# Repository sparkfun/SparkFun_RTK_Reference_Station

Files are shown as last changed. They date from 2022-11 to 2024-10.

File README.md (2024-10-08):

SparkFun RTK Reference Station
========================================

<table class="table table-hover table-striped table-bordered">
  <tr align="center">
   <td></td>
  <tr align="center">
    <td><a href="https://www.sparkfun.com/products/22429">SparkFun RTK Reference Station (GPS-22429)</a></td>
  </tr>
</table>

The RTK Reference Station from SparkFun is our most capable GNSS receiver and logger to date. It's your one stop shop for high precision geolocation, surveying and time reference needs. For basic users, it is incredibly easy to get up and running; for advanced users, the Reference Station is a flexible and powerful tool. We took everything we learned while developing our other RTK products, refined it and the Reference Station is the end result.

Is this just a [RTK Facet](https://www.sparkfun.com/products/19984) in a metal box? Oh no! It is _so_ much more... Sure, it is based on the same ESP32-WROOM processor and u-blox ZED-F9P multi-band GNSS module as the Facet. And it runs the same core firmware as the rest of the RTK product family. But there the similarities end. The Reference Station has 10/100 Mbps Ethernet connectivity provided by a WIZnet W5500 and it can be powered by Power-over-Ethernet (PoE) too. With just a few minutes of setup and survey-in, your Reference Station can be serving RTCM correction data to an NTRIP caster of your choice, all via Ethernet!

Need an affordable Network Time Protocol time server for your Ethernet network? We've got you covered. The Reference Station can act as a NTP server. It supports DHCP by default, but you can give it a fixed IP address if you want to. DNS, gateway and subnet mask are all configurable too.

The Reference Station gets a big speed boost too. The microSD card socket is connected via full 4-bit SDIO instead of the usual SPI, providing an order or magnitude improvement in read and write speeds. Similarly, the u-blox ZED-F9P GNSS module is connected via SPI instead of the usual I2C, also providing an order of magnitude improvement in data transfer speeds. Need to log RAWX and SFRBX at 20Hz? You can with the Reference Station!

Repository Contents
-------------------

* [**/Reference_Station_Test_Sketches**](/Reference_Station_Test_Sketches/) - Stand-alone Arduino test sketches for the Reference Station
* [**/Hardware**](/Hardware/) - Eagle PCB files, schematic and dimensions
* [**/Enclosure**](/Enclosure/) - Mechanical drawings for the custom extruded aluminium case and machined panels
* [**/Front_Panel**](/Front_Panel/) - Eagle PCB files for the prototype (fit-check) front panel
* [**/Rear_Panel**](/Rear_Panel/) - Eagle PCB files for the prototype (fit-check) rear panel
* [**/Front_Panel_Sticker**](/Front_Panel_Sticker/) - Drawings and prototype (fit-check) files for the front sticker
* [**/Rear_Panel_Sticker**](/Rear_Panel_Sticker/) - Drawings and prototype (fit-check) files for the rear sticker
* [**/Sticker_Alignment_Jig__Panel**](/Sticker_Alignment_Jig__Panel/) - Eagle PCB files for the two-piece sticker alignment jig
* [**/Sticker_Alignment_Jig__Sticker**](/Sticker_Alignment_Jig__Sticker/) - Eagle PCB files for the two-piece sticker alignment jig

Documentation
--------------

* **[RTK Product Manual](https://docs.sparkfun.com/SparkFun_RTK_Firmware/)** - A detailed guide describing all the various software features of the RTK product line. Essentially it is a manual for the firmware used by the RTK Reference Station.
* **[RTK Reference Station Hookup Guide](https://learn.sparkfun.com/tutorials/sparkfun-rtk-reference-station-hookup-guide)** - Hookup guide for the SparkFun RTK Reference Station.

License Information
-------------------

This product is _**open source**_! 

Please review the LICENSE.md file for license information. 

If you have any questions or concerns on licensing, please contact technical support on our [SparkFun forums](https://forum.sparkfun.com/viewforum.php?f=152).

Distributed as-is; no warranty is given.

- Your friends at SparkFun.

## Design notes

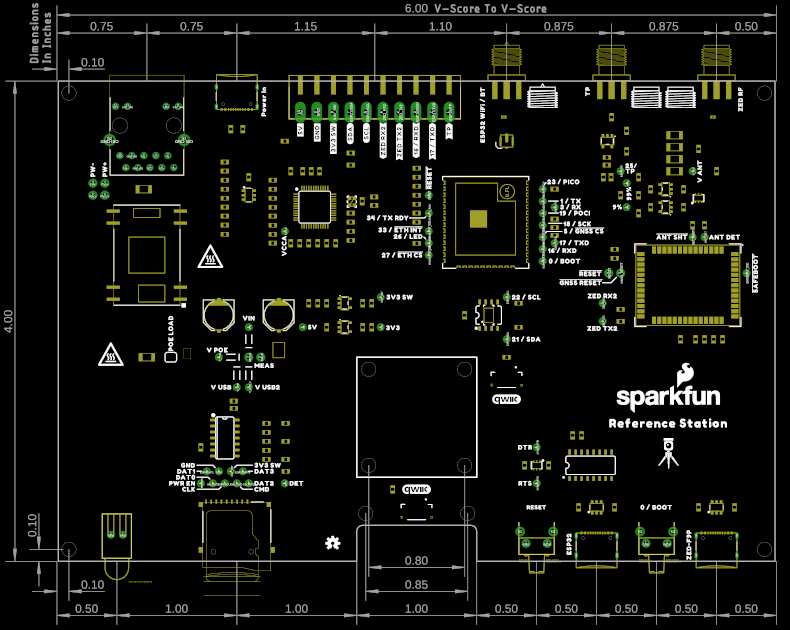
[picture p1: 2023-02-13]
Hardware/Dimensions.png

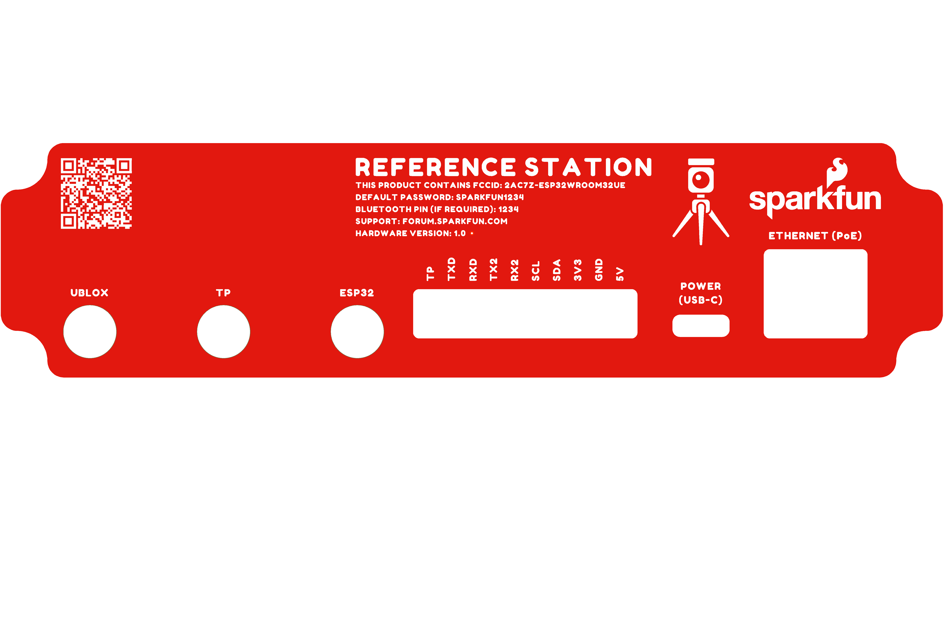
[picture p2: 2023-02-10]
Rear_Panel_Sticker/CORS_Rear_Panel_Sticker.png

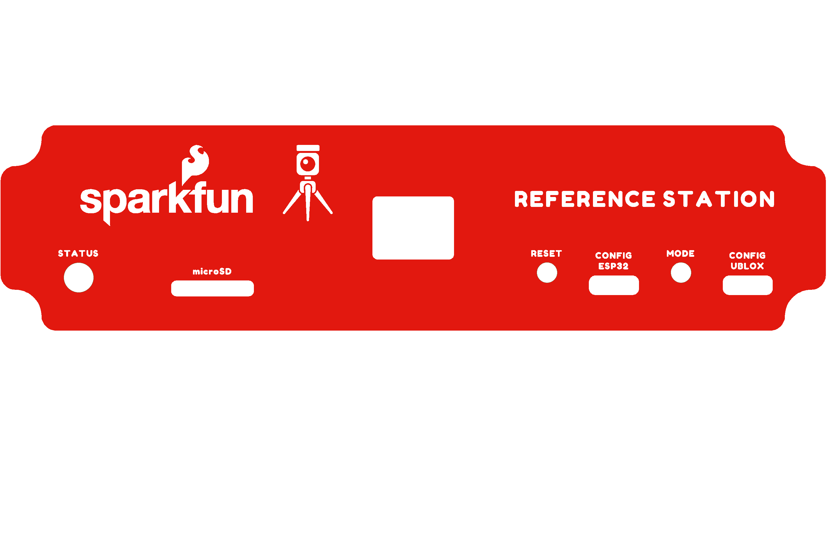
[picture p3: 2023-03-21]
Front_Panel_Sticker/CORS_Front_Panel_Sticker.png

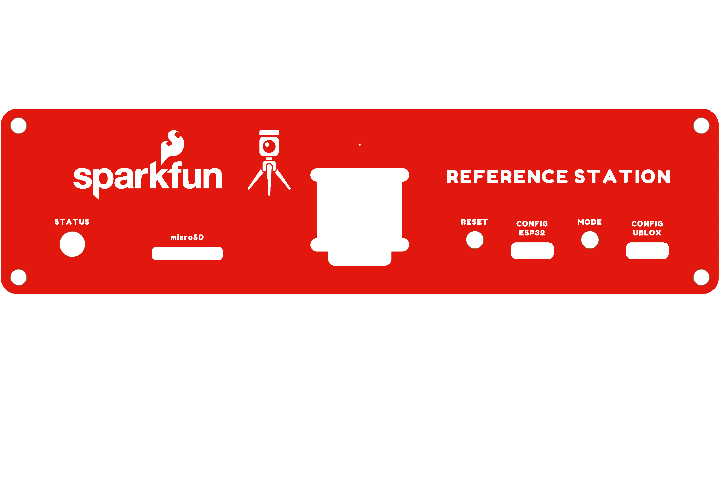
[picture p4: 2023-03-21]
Front_Panel/CORS_Front_Panel.png

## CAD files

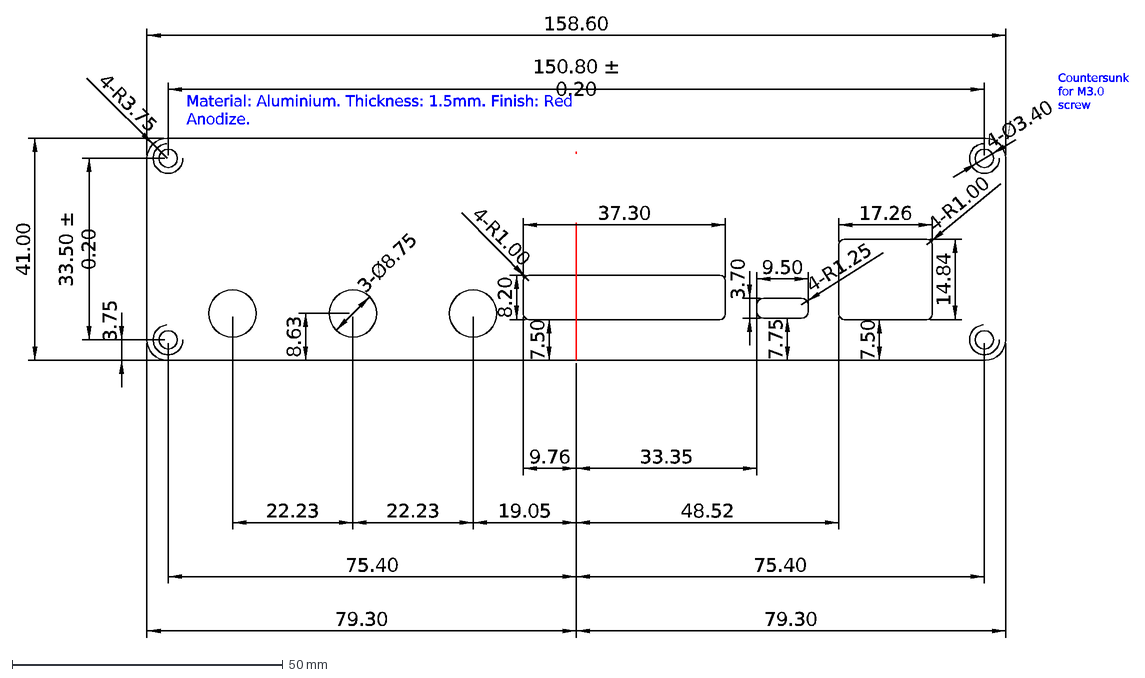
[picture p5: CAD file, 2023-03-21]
Enclosure/SparkFun_HF-A_Custom__Rear_Panel__v3.dxf
158.60
4-R3.75
150.80 ± 0.20
33.50 ± 0.20
41.00
9.76
37.30
7.50
8.20
4-R1.00
33.35
9.50
7.75
3.70
48.52
17.26
14.84
4-R1.25
19.05
22.23
8.63
79.30
75.40
3.75
3-Ø8.75
4-Ø3.40
Countersunk for M3.0 screw
Material: Aluminium. Thickness: 1.5mm. Finish: Red Anodize.

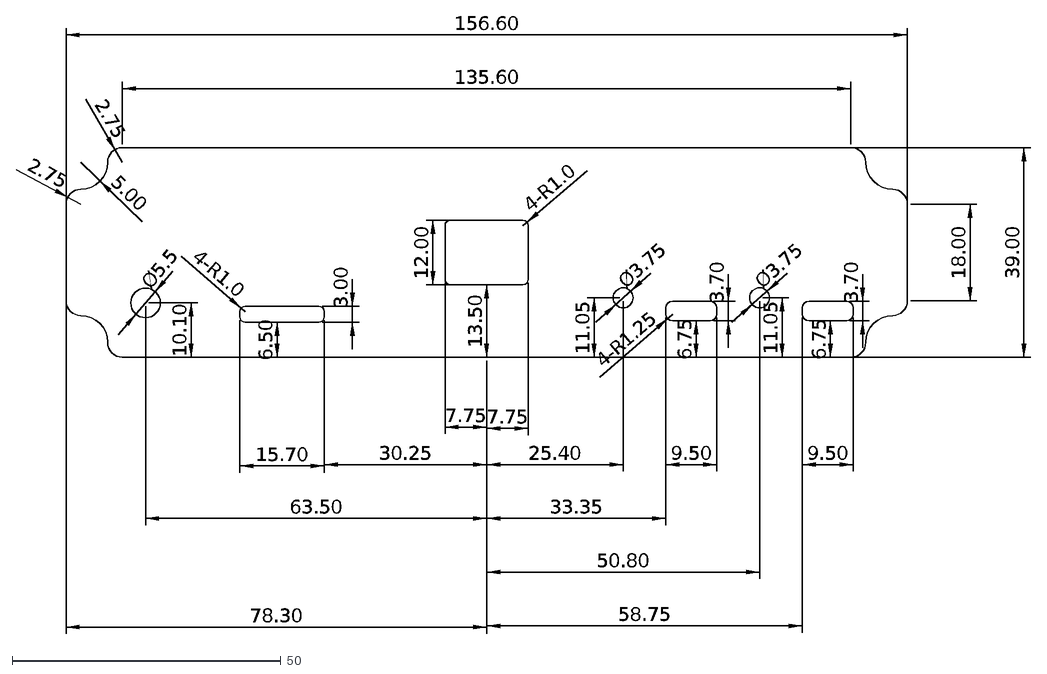
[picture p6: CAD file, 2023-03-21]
Front_Panel_Sticker/Front_Sticker_DXF_R14_v2.dxf
7.75
13.50
12.00
4-R1.0
30.25
15.70
6.50
3.00
63.50
10.10
Ø5.5
25.40
11.05
Ø3.75
33.35
9.50
6.75
3.70
50.80
58.75
78.30
156.60
39.00
2.75
5.00
135.60
18.00
4-R1.25

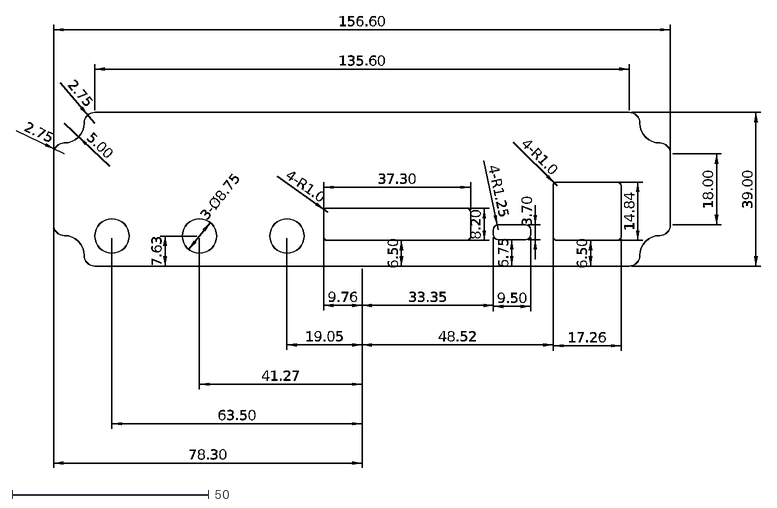
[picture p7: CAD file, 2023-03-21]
Rear_Panel_Sticker/Rear_Sticker_DXF_R14_v2.dxf
9.76
37.30
6.50
8.20
33.35
9.50
6.75
3.70
4-R1.0
19.05
41.27
63.50
7.63
3-Ø8.75
48.52
17.26
14.84
4-R1.25
78.30
135.60
156.60
39.00
18.00
2.75
5.00

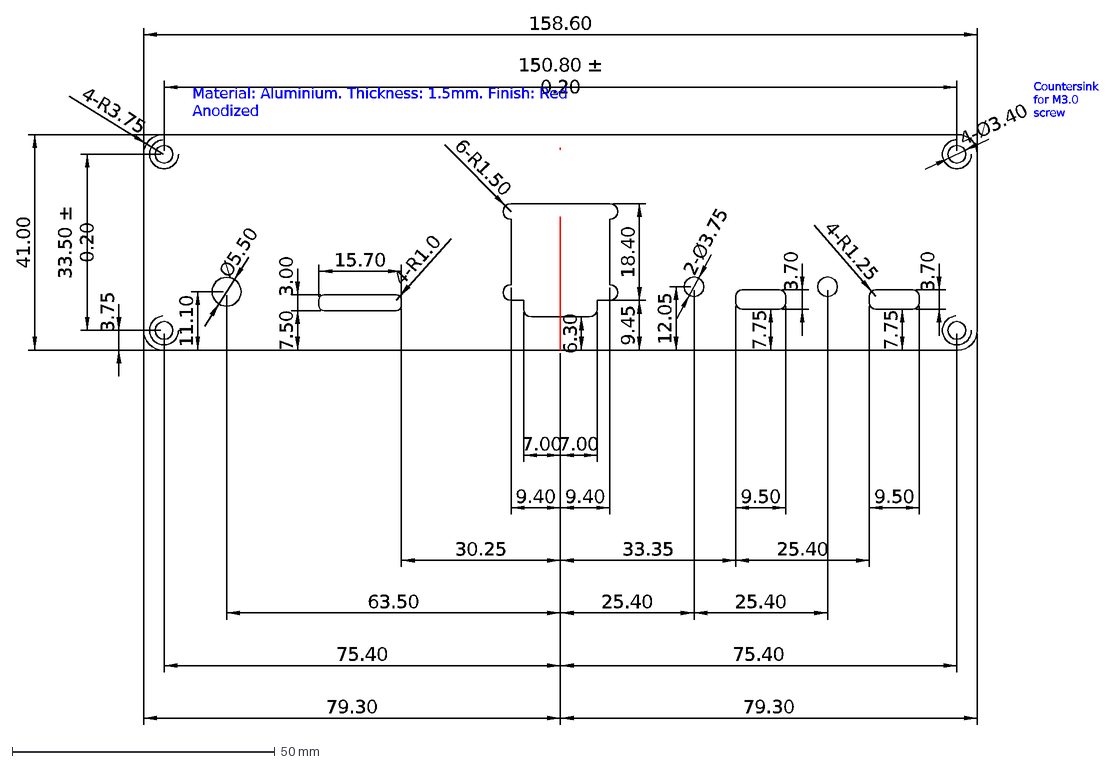
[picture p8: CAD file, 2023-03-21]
Enclosure/SparkFun_HF-A_Custom__Front_Panel__v3.dxf
41.00
158.60
4-R3.75
63.50
11.10
Ø5.50
25.40
3.00
15.70
30.25
7.50
4-R1.0
33.35
9.50
3.70
7.75
4-R1.25
12.05
2-Ø3.75
7.00
9.40
6.30
9.45
18.40
6-R1.50
4-Ø3.40
Countersink for M3.0 screw
33.50 ± 0.20
150.80 ± 0.20
3.75
75.40
79.30
Material: Aluminium. Thickness: 1.5mm. Finish: Red Anodized

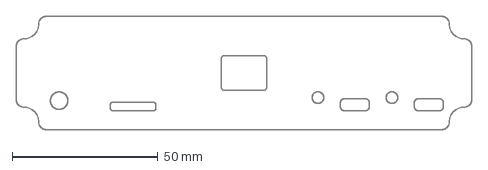
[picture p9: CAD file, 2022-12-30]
Front_Panel_Sticker/CORS_Front_Panel_Sticker.dxf
156.6 x 39.0 mm

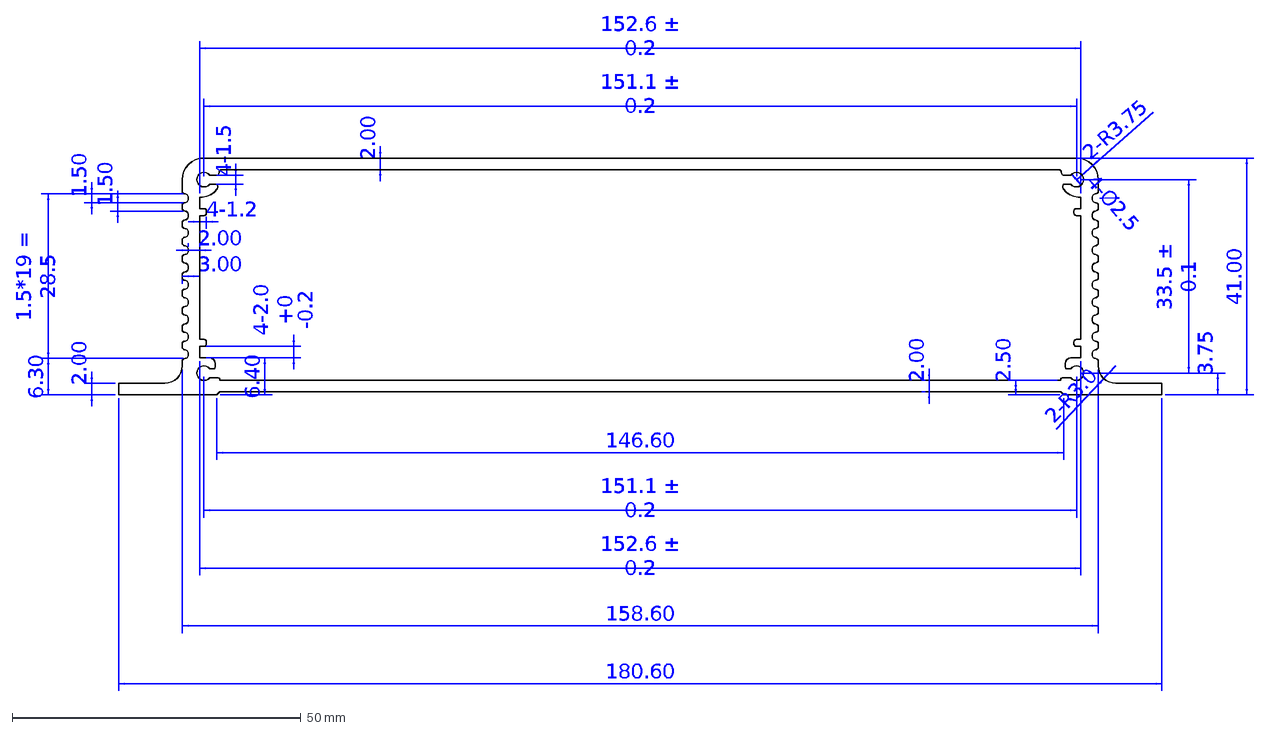
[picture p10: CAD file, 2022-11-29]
Enclosure/SparkFun_HF-A_Custom__Crossection__v3.dxf
1.5*19 = 28.5
6.30
1.50
180.60
158.60
3.00
4-1.5
4-1.2
2.00
2-R3.75
4-Ø2.5
6.40
4-2.0+0^-0.2
151.1 ± 0.2
152.6 ± 0.2
2.50
33.5 ± 0.1
3.75
41.00
146.60
2-R3.0

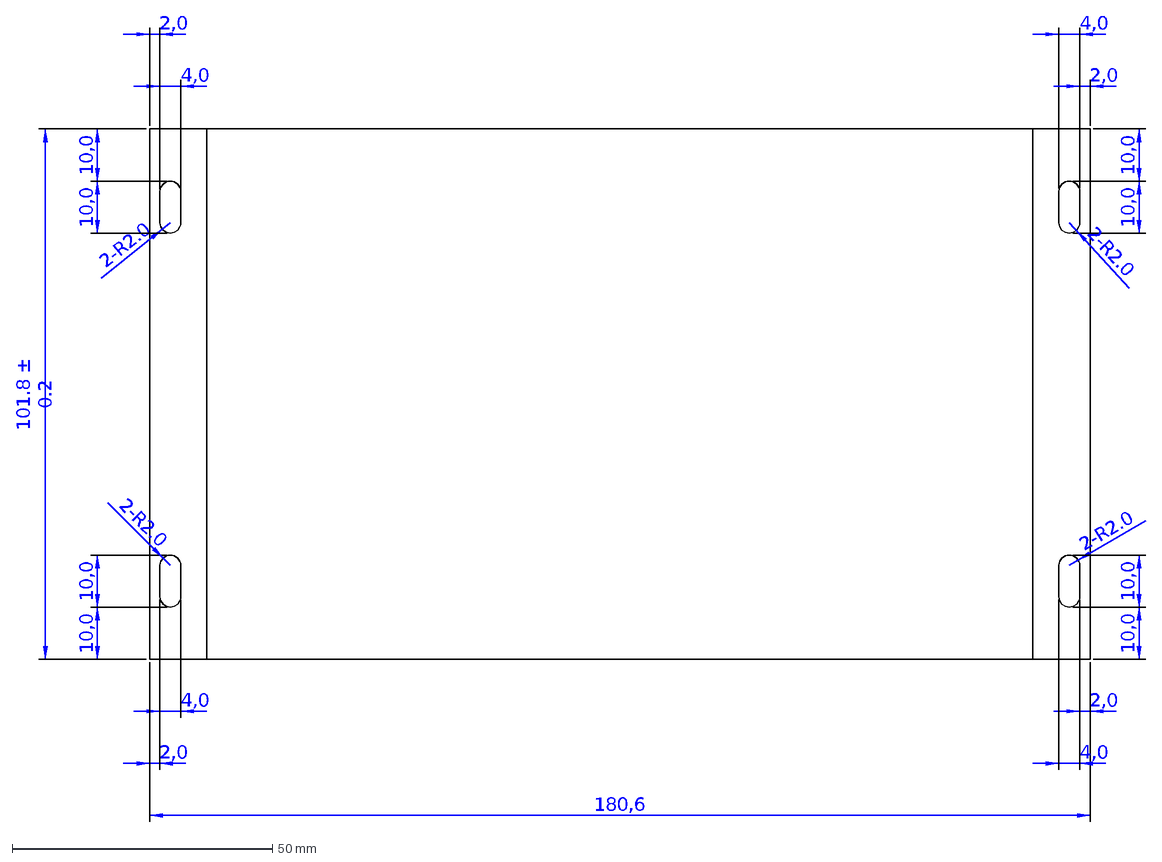
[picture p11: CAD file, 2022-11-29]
Enclosure/SparkFun_HF-A_Custom__Top_View__v3.dxf
101.8 ± 0.2
10,0
4,0
2,0
180,6
2-R2.0

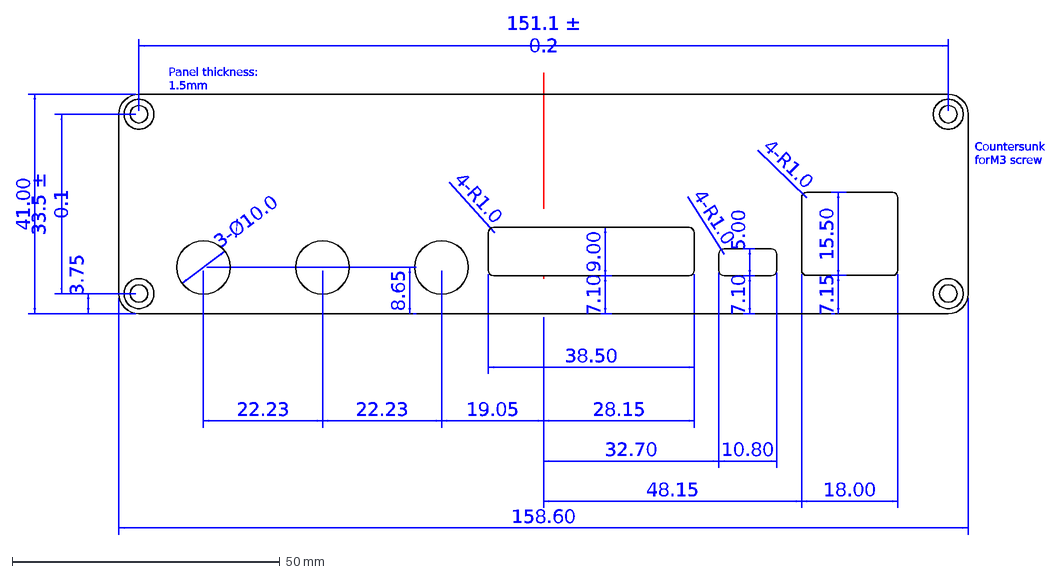
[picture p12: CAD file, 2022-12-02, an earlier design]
Enclosure/SparkFun_HF-A_Custom__Rear_Panel__v2.dxf
19.05
48.15
158.60
18.00
28.15
38.50
Countersunk for M3 screw
Panel thickness: 1.5mm
3.75
41.00
33.5 ± 0.1
151.1 ± 0.2
8.65
3-Ø10.0
4-R1.0
9.00
7.10
15.50
7.15
32.70
10.80
5.00
22.23

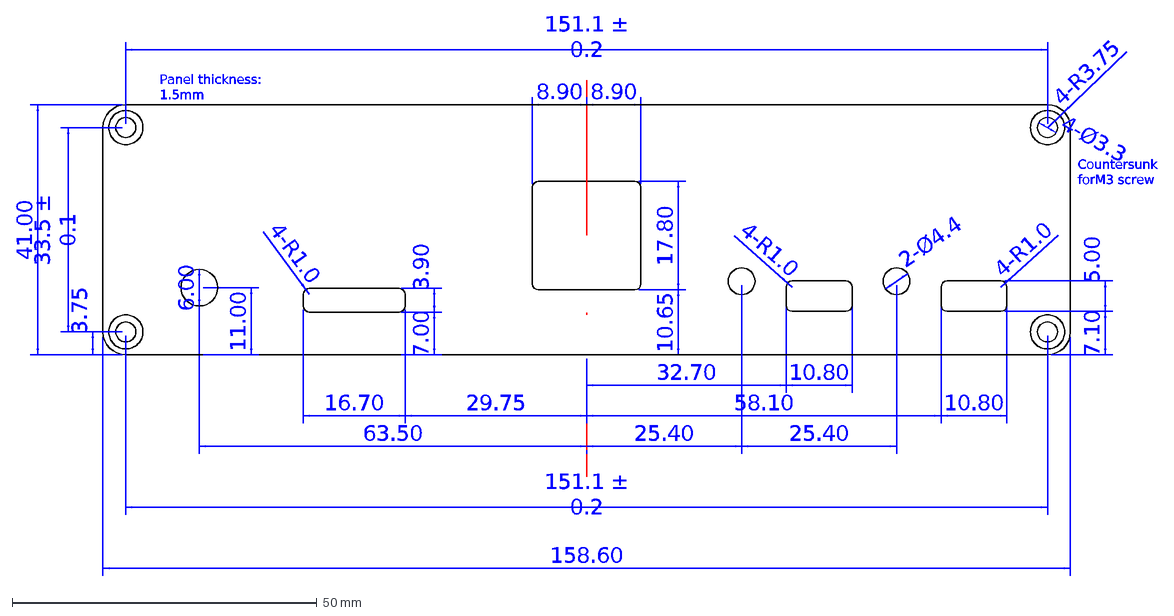
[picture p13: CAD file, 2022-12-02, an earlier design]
Enclosure/SparkFun_HF-A_Custom__Front_Panel__v2.dxf
Countersunk for M3 screw
158.60
63.50
58.10
10.80
8.90
17.80
10.65
32.70
Panel thickness: 1.5mm
41.00
33.5 ± 0.1
151.1 ± 0.2
4-Ø3.3
4-R3.75
11.00
6.00
4-R1.0
5.00
7.10
25.40
2-Ø4.4
29.75
16.70
7.00
3.90
3.75

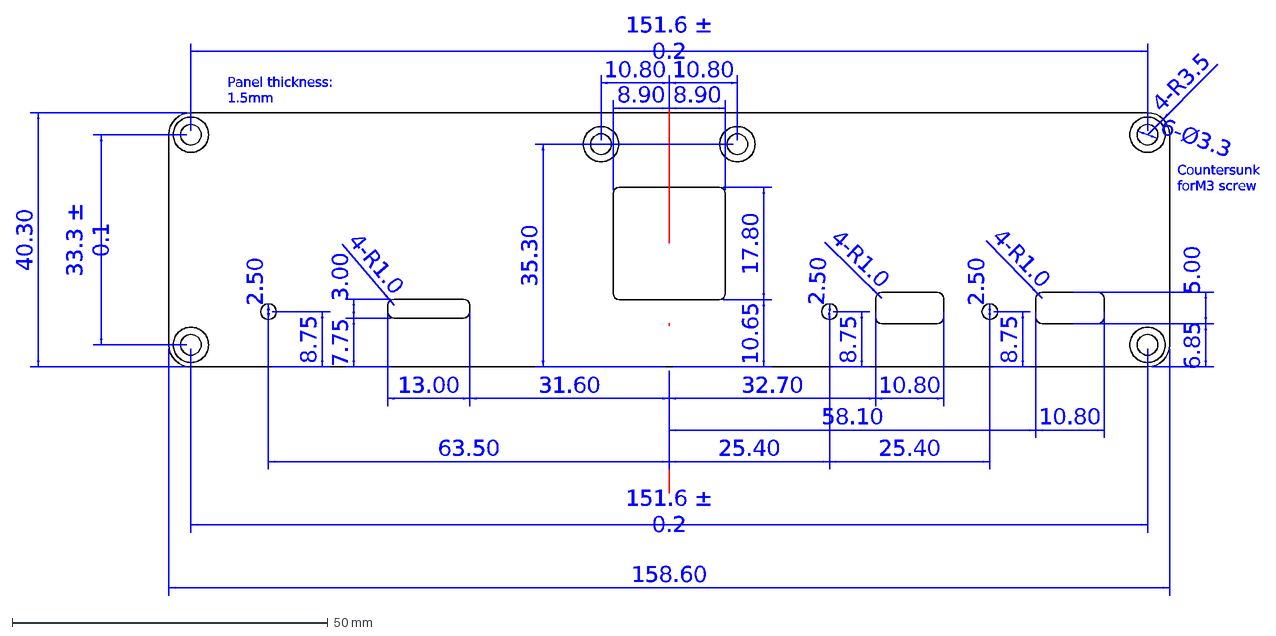
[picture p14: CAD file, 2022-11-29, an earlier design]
Enclosure/SparkFun_HF-A_Custom__Front_Panel.dxf
Countersunk for M3 screw
40.30
158.60
151.6 ± 0.2
63.50
25.40
58.10
10.80
8.75
2.50
4-R1.0
5.00
6.85
6-Ø3.3
4-R3.5
8.90
35.30
17.80
10.65
32.70
31.60
13.00
7.75
3.00
33.3 ± 0.1
Panel thickness: 1.5mm

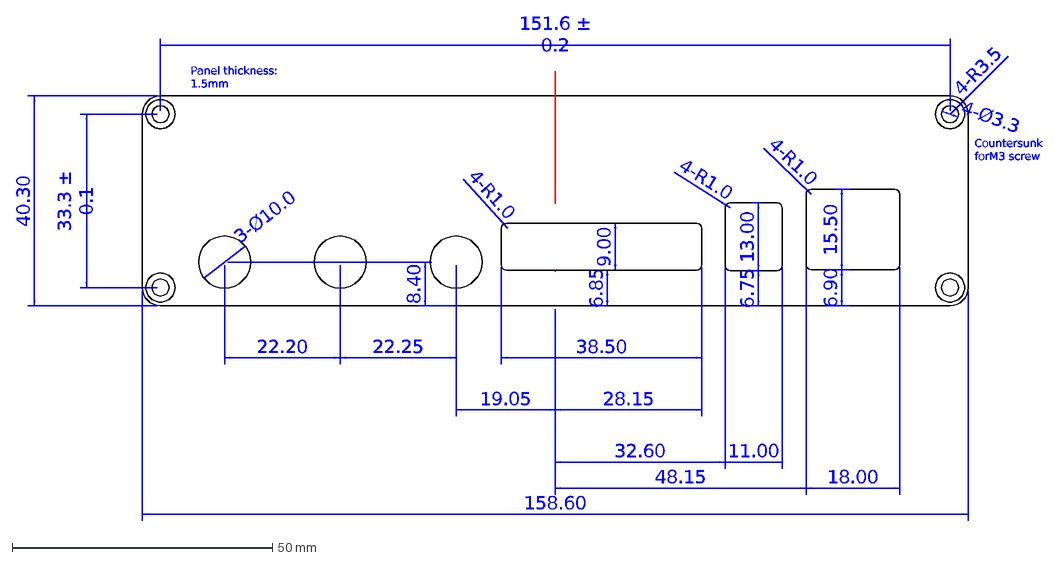
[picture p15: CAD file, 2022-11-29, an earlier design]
Enclosure/SparkFun_HF-A_Custom__Rear_Panel.dxf
40.30
3-Ø10.0
22.20
22.25
8.40
19.05
4-R1.0
9.00
6.85
32.60
48.15
158.60
13.00
6.75
11.00
15.50
6.90
18.00
4-R3.5
4-Ø3.3
151.6 ± 0.2
28.15
38.50
33.3 ± 0.1
Countersunk for M3 screw
Panel thickness: 1.5mm

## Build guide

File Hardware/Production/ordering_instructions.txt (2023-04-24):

panel size, 166x126mm
JLCPCB JLC-7628 Impedance Control
PCB thickness, 1.6mm
number of layers, 4
soldermask color, Red
silkscreen color, White
oz copper, 1oz
finish, HASL lead free
stencils, top
pcs per panel, 1
min trace width, 0.1524mm / 0.0060in
min drill size, 0.3000mm / 0.0118in
filename to layer stackup 1/2/3/4: GTL, GL2, GL3, GBL

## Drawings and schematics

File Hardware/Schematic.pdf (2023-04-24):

# IOA27 12 SCK2/IOA14 13 POCI2/IOA12 14 PICO2/IOA13 16 PICO3/IO23 37 SCL/IO22 36

# TX-IO1 35 RX-IO3 34 SDA/IO21 33 POCI3/IO19 31 SCK3/IO18 30 CS3/IO5 29

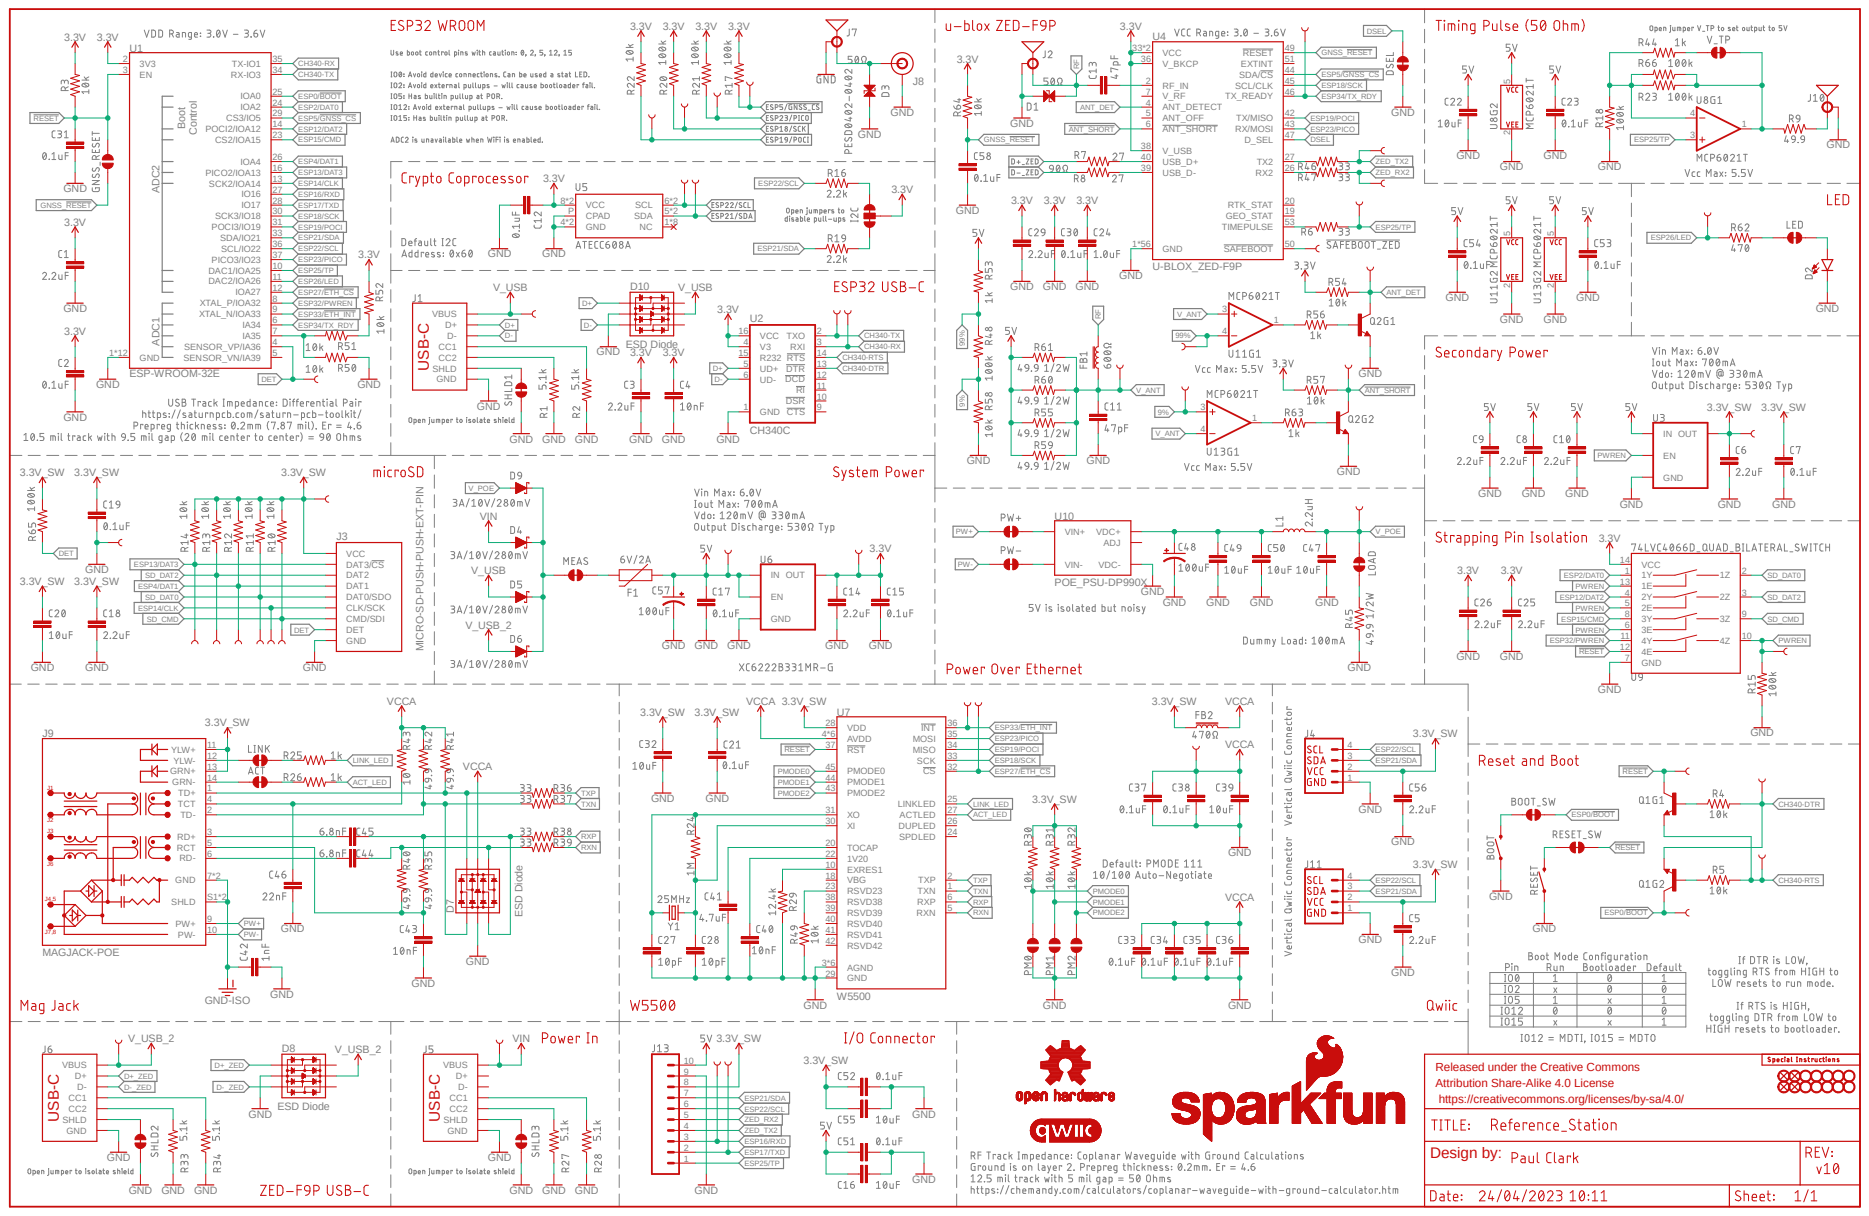
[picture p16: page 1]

DAT2 DAT1 CLK/SCK DET VCC
DAT3/CS CMD/SDI DAT0/SDO

U7 TD+ 1 TCT 4 TD- 2 RD+ 3 RCT 5 RD- 6 GND 7*2 SHLD S1*2 PW+ 9 PW- 10 YLW+ 11 YLW- 12 GRN+ 13 GRN- 14

TXN 1 TXP 2 RXN 5 RXP 6 EXRES1 10 AVDD 4*6 VBG 18 TOCAP 20

Released under the Creative Commons
Attribution Share-Alike 4.0 License
https://creativecommons.org/licenses/by-sa/4.0/

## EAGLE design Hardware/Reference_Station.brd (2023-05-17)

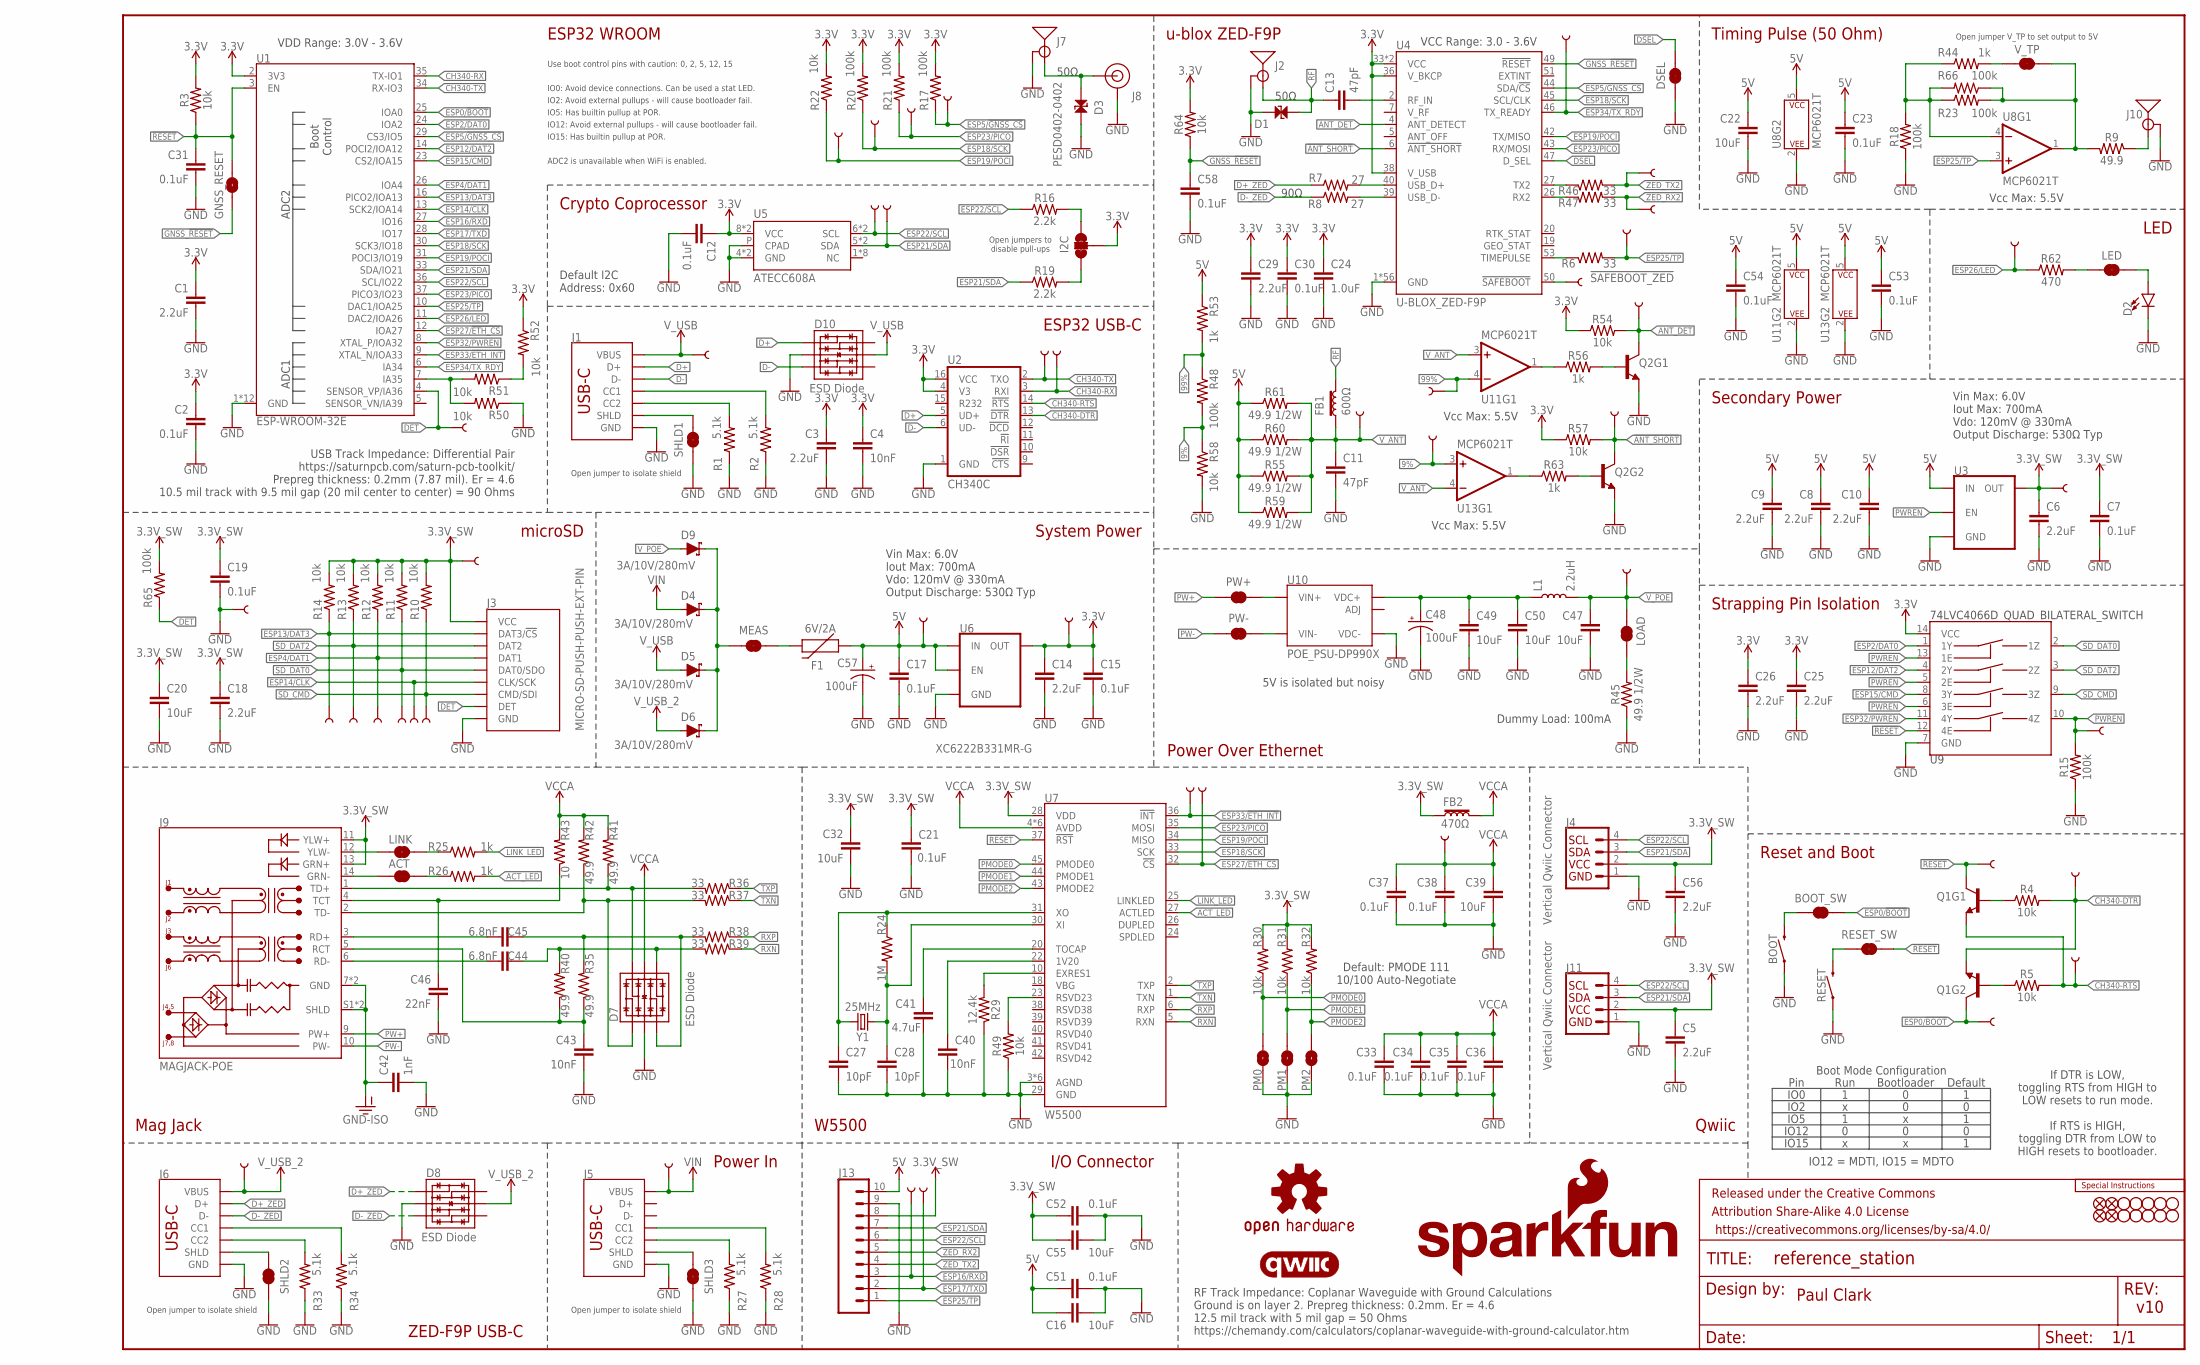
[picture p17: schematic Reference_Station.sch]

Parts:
3V3, 3V3_SW, 5V, 9%, 99%: TEST-POINTPOGO_PTH; 1X01_NO_SILK
!SAFEBOOT_ZED!: TEST-POINTPOGO_PTH; 1X01_NO_SILK
ACT: JUMPER-SMT_2_NC_TRACE_SILK; SMT-JUMPER_2_NC_TRACE_SILK
ANT_DET: TEST-POINTPOGO_PTH; 1X01_NO_SILK
ANT_SHT: TEST-POINTPOGO_PTH; 1X01_NO_SILK
BOOT: MOMENTARY-SWITCH-SPST-PTH-RIGHT-ANGLE-8-020; TACTILE_SWITCH_PTH_RA_8-020
BOOT_SW: JUMPER-SMT_2_NC_TRACE_SILK; SMT-JUMPER_2_NC_TRACE_SILK
C1, C3, C5, C6, C8, C9, C10, C14, C18, C25, C26, C29, C56: 2.2uF; 0603
C2, C7, C12, C15, C17, C19, C21, C23, C30, C31, C33, C34, C35, C36, C37, C38, C51, C52, C53, C54, C58: 0.1uF; 0603
C4, C40, C43: 10nF; 0603
C11, C13: 47pF; 0603
C16, C47, C49, C50: 10uF; 0805
C20, C22, C32, C39, C55: 10uF; 0603
C24: 1.0uF; 0603
C27, C28: 10pF; 0603
C41: 4.7uF; 0603
C42: 1nF; 1206
C44, C45: 6.8nF; 0603
C46: 22nF; 0603
C48, C57: 100uF; PANASONIC_D
CLK: TEST-POINTPOGO_PTH; 1X01_NO_SILK
CMD, CMD1: TEST-POINTPOGO_PTH; 1X01_NO_SILK
D1, D3: PESD0402-0402; 0402
D2: LED-RIGHT-ANGLE-PTH-GREEN; CBI-RIGHT-ANGLE-PTH
D4, D5, D6, D9: 3A/10V/280mV; SOD-323
D7, D8, D10: ESD Diode; SOT-23-6
DAT0, DAT1, DAT2, DAT3: TEST-POINTPOGO_PTH; 1X01_NO_SILK
DET: TEST-POINTPOGO_PTH; 1X01_NO_SILK
DSEL: JUMPER-SMT_2_NC_TRACE_SILK; SMT-JUMPER_2_NC_TRACE_SILK
DTR: TEST-POINTPOGO_PTH; 1X01_NO_SILK
ETH_CS: TEST-POINTPOGO_PTH; 1X01_NO_SILK
ETH_INT: TEST-POINTPOGO_PTH; 1X01_NO_SILK
F1: 6V/2A; 1210
FB1: 600Ω; 0805
FB2: 470Ω; 0603
FD1, FD2, FD3, FD4: FIDUCIAL1X2; FIDUCIAL-1X2
FRAME1: FRAME-LEDGER; CREATIVE_COMMONS
GND: TEST-POINTPOGO_PTH; 1X01_NO_SILK
GNSS_CS: TEST-POINTPOGO_PTH; 1X01_NO_SILK
GNSS_RESET: JUMPER-COMBO_2_NO; COMBO-JUMPER_2_NO
H1, H2, H3, H4, H5, H6, H7, H8, H9, H10: STAND-OFFTIGHT; STAND-OFF-TIGHT
I2C: JUMPER-SMT_3_2-NC_TRACE_SILK; SMT-JUMPER_3_2-NC_TRACE_SILK
J1, J5, J6: USB_C_4-LAYER_PADS; USB-C-16P_4LAYER-PADS
J2, J10: ANTENNA-SMA-GROUNDEDEDGE_SMA; SMA-EDGE
J3: MICRO-SD-PUSH-PUSH-EXT-PIN; MICROSD-EXTERNALPIN
J4, J11: Vertical Qwiic Connector; JST04_1MM_VERT
J7: ANTENNA-SMA-GROUNDEDEDGE_RPSMA; RP-SMA-EDGE
J8: U.FL2PIN-REDUCED-FOOTPRINT; U.FL_REDUCED_FOOTPRINT
J9: MAGJACK-POE; MAGJACK-SYM_LED
J13: CONN_10_3.5MM_RA_HEADER; 1X10_SCREW_TERMINAL_3.5MM
L1: 2.2uH; 0805-WIDE
LED: JUMPER-SMT_2_NC_TRACE_SILK; SMT-JUMPER_2_NC_TRACE_SILK
LINK: JUMPER-SMT_2_NC_TRACE_SILK; SMT-JUMPER_2_NC_TRACE_SILK
LOAD: JUMPER-SMT_2_NC_TRACE_SILK; SMT-JUMPER_2_NC_TRACE_SILK
LOGO1: SPECIAL_INSTRUCTIONS-ORDERING; ORDERING_INSTRUCTIONS
LOGO3: QWIIC_LOGO_6MM; QWIIC_6MM
LOGO4: OSHW-LOGOS; OSHW-LOGO-S
LOGO5: SFE_LOGO_NAME.2_INCH; SFE_LOGO_NAME_.2
LOGO6: SFE_LOGO_FLAME.2_INCH; SFE_LOGO_FLAME_.2
MEAS: JUMPER-COMBO_2_NC_TRACE; COMBO-JUMPER_2_NC_TRACE
PICO: TEST-POINTPOGO_PTH; 1X01_NO_SILK
PM0, PM1, PM2: JUMPER-SMT_2_NO_SILK; SMT-JUMPER_2_NO_SILK
POCI: TEST-POINTPOGO_PTH; 1X01_NO_SILK
PW+: JUMPER-COMBO_2_NC_TRACE; COMBO-JUMPER_2_NC_TRACE
PW-: JUMPER-COMBO_2_NC_TRACE; COMBO-JUMPER_2_NC_TRACE
PWREN: TEST-POINTPOGO_PTH; 1X01_NO_SILK
Q1, Q2: TRANS_NPN_DUAL-MBT3904DW1T1; SC70-6
R1, R2, R27, R28, R33, R34: 5.1k; 0603
R3, R4, R5, R10, R11, R12, R13, R14, R22, R30, R31, R32, R49, R50, R51, R52, R54, R57, R58, R64: 10k; 0603
R6, R36, R37, R38, R39, R46, R47: 33; 0603
R7, R8: 27; 0603
R9, R35, R40, R41, R42: 49.9; 0603
R15, R17, R18, R20, R21, R23, R48, R65, R66: 100k; 0603
R16, R19: 2.2k; 0603
R24: 1M; 0603
R25, R26, R44, R53, R56, R63: 1k; 0603
R29: 12.4k; 0603
R43: 10; 0603
R45, R55, R59, R60, R61: 49.9 1/2W; 1206
R62: 470; 0603
RESET: MOMENTARY-SWITCH-SPST-PTH-RIGHT-ANGLE-8-020; TACTILE_SWITCH_PTH_RA_8-020
RESET_SW: JUMPER-SMT_2_NC_TRACE_SILK; SMT-JUMPER_2_NC_TRACE_SILK
RTS: TEST-POINTPOGO_PTH; 1X01_NO_SILK
RX, RX2: TEST-POINTPOGO_PTH; 1X01_NO_SILK
RXD: TEST-POINTPOGO_PTH; 1X01_NO_SILK
SCK: TEST-POINTPOGO_PTH; 1X01_NO_SILK
SCL: TEST-POINTPOGO_PTH; 1X01_NO_SILK
SDA: TEST-POINTPOGO_PTH; 1X01_NO_SILK
SHLD1, SHLD2, SHLD3: JUMPER-SMT_2_NC_TRACE_SILK; SMT-JUMPER_2_NC_TRACE_SILK
TP: TEST-POINTPOGO_PTH; 1X01_NO_SILK
TP_BOOT: TEST-POINTPOGO_PTH; 1X01_NO_SILK
TP_LED: TEST-POINTPOGO_PTH; 1X01_NO_SILK
TP_RESET: TEST-POINTPOGO_PTH; 1X01_NO_SILK
TX, TX2: TEST-POINTPOGO_PTH; 1X01_NO_SILK
TXD: TEST-POINTPOGO_PTH; 1X01_NO_SILK
TX_RDY: TEST-POINTPOGO_PTH; 1X01_NO_SILK
U1: ESP-WROOM-32E; ESP-WROOM-32EU
U2: CH340C; SO016
U3, U6: XC6222B331MR-G; SOT23-5
U4: U-BLOX_ZED-F9P; ZED-F9P
U5: ATECC608A; DUAL_UDFN_2X3MM_SOIC-8
U7: W5500; LQFP-48
U8, U11, U13: MCP6021T; SOT23-5
U9: 74LVC4066D_QUAD_BILATERAL_SWITCH; SO14
U10: POE_PSU-DP990X; DP990X
VANT: TEST-POINTPOGO_PTH; 1X01_NO_SILK
VCCA: TEST-POINTPOGO_PTH; 1X01_NO_SILK
VIN: TEST-POINTPOGO_PTH; 1X01_NO_SILK
VPOE: TEST-POINTPOGO_PTH; 1X01_NO_SILK
VUSB, VUSB2: TEST-POINTPOGO_PTH; 1X01_NO_SILK
V_TP: JUMPER-SMT_2_NC_TRACE_SILK; SMT-JUMPER_2_NC_TRACE_SILK
Y1: 25MHz; CRYSTAL-SMD-2.0X1.6MM

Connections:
3.3V: 3V3.1, C1.1, C2.1, C3.1, C4.1, C12.1, C14.1, C15.1, C24.1, C25.1, C26.1, C29.1, C30.1, I2C.2, R3.2, R17.2, R20.2, R21.2, R22.2, R52.1, R54.1, R57.1, R64.2, U1.2 (3V3), U2.4 (V3), U2.16 (VCC), U4.33 (VCC), U4.34 (VCC), U4.36 (V_BKCP), U4.38 (V_USB), U5.8 (VCC), U5.8S (VCC), U6.5 (OUT), U9.14 (VCC)
3.3V_SW: 3V3_SW.1, C5.1, C6.1, C7.1, C18.1, C19.1, C20.1, C21.1, C32.1, C52.1, C55.1, C56.1, CMD1.1, FB2.1, J3.4 (VCC), J4.2, J9.11 (YLW+), J9.13 (GRN+), J11.2, J13.8, R10.2, R11.2, R12.2, R13.2, R14.2, R30.2, R31.2, R32.2, R65.2, U3.5 (OUT), U7.28 (VDD)
5V: 5V.1, C8.1, C9.1, C10.1, C16.1, C17.1, C22.1, C23.1, C51.1, C53.1, C54.1, C57.+, F1.1, J13.10, R53.1, R55.1, R59.1, R60.1, R61.1, U3.1 (IN), U6.1 (IN), U6.3 (EN), U8.5 (P$V+), U11.5 (P$V+), U13.5 (P$V+)
5V_RAW: C48.+, C49.1, C50.1, L1.1, U10.1 (VDC+), U10.2 (VDC+)
9%: 9%.1, R48.2, R58.1, U13.3 (+IN)
99%: 99%.1, R48.1, R53.2, U11.4 (-IN)
!ANT_SHORT!: ANT_SHT.1, Q2.6 (C), R57.2, U4.6 (!ANT_SHORT!)
!RESET!: C31.1, GNSS_RESET.2, GNSS_RESET.4 (2), Q1.3 (C), R3.1, RESET_SW.1, TP_RESET.1, U1.3 (EN), U7.37 (!RST!), U9.12 (4E)
!SAFEBOOT_ZED!: !SAFEBOOT_ZED!.1, U4.50 (!SAFEBOOT!)
ACT: ACT.1, J9.14 (GRN-)
ACT_LED: R26.2, U7.27 (ACTLED)
ANT_DET: ANT_DET.1, Q2.3 (C), R54.2, U4.4 (ANT_DETECT)
CH340-DTR: DTR.1, Q1.1 (E), R4.2, U2.13 (!DTR)
CH340-RTS: Q1.4 (E), R5.2, RTS.1, U2.14 (!RTS)
CH340-RX: TX.1, U1.35 (TX-IO1), U2.3 (RXI)
CH340-TX: RX.1, U1.34 (RX-IO3), U2.2 (TXO)
D+: D10.1 (IO1), J1.A6 (D+), J1.B6 (D+), U2.5 (UD+)
D+_ZED: D8.1 (IO1), J6.A6 (D+), J6.B6 (D+), R7.1
D-: D10.3 (IO2), J1.A7 (D-), J1.B7 (D-), U2.6 (UD-)
D-_ZED: D8.3 (IO2), J6.A7 (D-), J6.B7 (D-), R8.1
DET: DET.1, J3.9 (DET), R65.1, U1.4 (SENSOR_VP/IA36)
DSEL: DSEL.2, U4.47 (D_SEL)
ESP0/!BOOT!: BOOT_SW.1, Q1.6 (C), TP_BOOT.1, U1.25 (IOA0)
ESP2/DAT0: U1.24 (IOA2), U9.1 (1Y)
ESP4/DAT1: DAT1.1, J3.8 (DAT1), R12.1, U1.26 (IOA4)
ESP5/!GNSS_CS!: GNSS_CS.1, R17.1, U1.29 (CS3/IO5), U4.44 (SDA/!CS!)
ESP12/DAT2: U1.14 (POCI2/IOA12), U9.4 (2Y)
ESP13/DAT3: DAT3.1, J3.2 (DAT3/!CS!), R14.1, U1.16 (PICO2/IOA13)
ESP14/CLK: CLK.1, J3.5 (CLK/SCK), U1.13 (SCK2/IOA14)
ESP15/CMD: U1.23 (CS2/IOA15), U9.8 (3Y)
ESP16/RXD: J13.3, RXD.1, U1.27 (IO16)
ESP17/TXD: J13.2, TXD.1, U1.28 (IO17)
ESP18/SCK: R20.1, SCK.1, U1.30 (SCK3/IO18), U4.45 (SCL/CLK), U7.33 (SCK)
ESP19/POCI: POCI.1, R22.1, U1.31 (POCI3/IO19), U4.42 (TX/MISO), U7.34 (MISO)
ESP21/SDA: J4.3, J11.3, J13.7, R19.1, SDA.1, U1.33 (SDA/IO21), U5.5 (SDA), U5.5S (SDA)
ESP22/SCL: J4.4, J11.4, J13.6, R16.1, SCL.1, U1.36 (SCL/IO22), U5.6 (SCL), U5.6S (SCL)
ESP23/PICO: PICO.1, R21.1, U1.37 (PICO3/IO23), U4.43 (RX/MOSI), U7.35 (MOSI)
ESP25/TP: J13.1, R6.2, TP.1, U1.10 (DAC1/IOA25), U8.3 (+IN)
ESP26/LED: R62.1, TP_LED.1, U1.11 (DAC2/IOA26)
ESP27/!ETH_CS!: ETH_CS.1, U1.12 (IOA27), U7.32 (!CS!)
ESP32/PWREN: U1.8 (XTAL_P/IOA32), U9.11 (4Y)
ESP33/!ETH_INT!: ETH_INT.1, U1.9 (XTAL_N/IOA33), U7.36 (!INT!)
ESP34/TX_RDY: TX_RDY.1, U1.6 (IA34), U4.46 (TX_READY)
GND: BOOT.1, C1.2, C2.2, C3.2, C4.2, C5.2, C6.2, C7.2, C8.2, C9.2, C10.2, C11.2, C12.2, C14.2, C15.2, C16.2, C17.2, C18.2, C19.2, C20.2, C21.2, C22.2, C23.2, C24.2, C25.2, C26.2, C27.2, C28.2, C29.2, C30.2, C31.2, C32.2, C33.2, C34.2, C35.2, C36.2, C37.2, C38.2, C39.2, C40.2, C41.2, C42.2, C43.2, C46.2, C47.2, C48.-, C49.2, C50.2, C51.2, C52.2, C53.2, C54.2, C55.2, C56.2, C57.-, C58.2, D1.2, D2.C, D3.2, D7.2 (VSS), D8.2 (VSS), D10.2 (VSS), DSEL.1, GND.1, J1.GND, J1.GND2 (GND), J2.GND@0 (GND), J2.GND@1 (GND), J2.GND@2 (GND), J2.GND@3 (GND), J3.6 (GND), J3.10 (GND), J3.11 (GND), J3.12 (GND), J3.13 (GND), J4.1, J5.GND, J5.GND2 (GND), J6.GND, J6.GND2 (GND), J7.GND@0 (GND), J7.GND@1 (GND), J7.GND@2 (GND), J7.GND@3 (GND), J8.1 (GND), J8.2 (GND), J10.GND@0 (GND), J10.GND@1 (GND), J10.GND@2 (GND), J10.GND@3 (GND), J11.1, J13.9, PM0.1, PM1.1, PM2.1, Q2.1 (E), Q2.4 (E), R1.1, R2.1, R15.1, R18.1, R27.1, R28.1, R29.1, R33.1, R34.1, R45.1, R49.1, R50.1, R58.2, RESET.1, SHLD1.1, SHLD2.1, SHLD3.1, U1.1 (GND), U1.15 (GND), U1.38 (GND), U1.GND, U1.GNDT1 (GND), U1.GNDT2 (GND), U1.GNDT3 (GND), U1.GNDT4 (GND), U1.GNDT5 (GND), U1.GNDT6 (GND), U1.GNDT7 (GND), U1.GNDT8 (GND), U2.1 (GND), U3.2 (GND), U4.1 (GND), U4.3 (GND), U4.12 (GND), U4.14 (GND), U4.32 (GND), U4.37 (GND), U4.41 (GND), U4.48 (GND), U4.55 (GND), U4.56 (GND), U4.57 (GND), U4.58 (GND), U4.59 (GND), U4.60 (GND), U4.61 (GND), U4.62 (GND), U4.63 (GND), U4.64 (GND), U4.65 (GND), U4.66 (GND), U4.67 (GND), U4.68 (GND), U4.69 (GND), U4.70 (GND), U4.71 (GND), U4.72 (GND), U4.73 (GND), U4.74 (GND), U4.75 (GND), U4.76 (GND), U4.77 (GND), U4.78 (GND), U4.79 (GND), U4.80 (GND), U4.81 (GND), U4.82 (GND), U4.83 (GND), U4.84 (GND), U4.85 (GND), U4.86 (GND), U4.87 (GND), U4.88 (GND), U4.89 (GND), U4.90 (GND), U4.91 (GND), U4.92 (GND), U4.93 (GND), U4.94 (GND), U4.95 (GND), U4.96 (GND), U4.97 (GND), U4.98 (GND), U4.99 (GND), U4.100 (GND), U4.101 (GND), U4.102 (GND), U5.4 (GND), U5.4S (GND), U5.P (CPAD), U6.2 (GND), U7.3 (AGND), U7.9 (AGND), U7.14 (AGND), U7.16 (AGND), U7.19 (AGND), U7.29 (GND), U7.48 (AGND), U8.2 (P$V-), U9.7 (GND), U10.3 (VDC-), U11.2 (P$V-), U13.2 (P$V-)
GND-ISO: C42.1, J9.7 (GND), J9.8 (GND), J9.S1 (SHLD), J9.S2 (SHLD)
GNSS_!RESET!: C58.1, GNSS_RESET.1, GNSS_RESET.3 (1), R64.1, U4.49 (!RESET!)
LINK: J9.12 (YLW-), LINK.1
LINK_LED: R25.2, U7.25 (LINKLED)
MEAS: D4.C, D5.C, D6.C, D9.C, MEAS.2, MEAS.4 (2)
unnamed: J1.B5 (CC2), R1.2
unnamed: J1.A5 (CC1), R2.2
unnamed: R7.2, U4.40 (USB_D+)
unnamed: Q1.2 (B), R5.1
unnamed: Q1.5 (B), R4.1
unnamed: R8.2, U4.39 (USB_D-)
unnamed: LED.2, R62.2
unnamed: J6.SHLD1 (SHLD), J6.SHLD2 (SHLD), J6.SHLD3 (SHLD), J6.SHLD4 (SHLD), SHLD2.2
unnamed: J5.B5 (CC2), R27.2
unnamed: F1.2, MEAS.1, MEAS.3 (1)
unnamed: R46.1, U4.27 (TX2)
unnamed: ACT.2, R26.1
unnamed: D3.1, J7.SIG (SIGNAL), J8.FEED (SIGNAL)
unnamed: I2C.3, R16.2
unnamed: I2C.1, R19.2
unnamed: J10.SIG (SIGNAL), R9.1
unnamed: R18.2, R23.1, R44.1, R66.2, U8.4 (-IN)
unnamed: C27.1, R24.1, U7.31 (XO), Y1.1
unnamed: C28.1, R24.2, U7.30 (XI), Y1.3 (2)
unnamed: LINK.2, R25.1
unnamed: J5.A5 (CC1), R28.2
unnamed: R29.2, U7.10 (EXRES1)
unnamed: C40.1, U7.22 (1V20)
unnamed: C41.1, U7.20 (TOCAP)
unnamed: R9.2, R23.2, R66.1, U8.1 (OUT), V_TP.2
unnamed: LOAD.1, R45.2
unnamed: RESET.2, RESET_SW.2
unnamed: BOOT.2, BOOT_SW.2
unnamed: R49.2, U7.23 (RSVD23)
unnamed: R44.2, V_TP.1
unnamed: R47.1, U4.26 (RX2)
unnamed: J6.B5 (CC2), R33.2
unnamed: J6.A5 (CC1), R34.2
unnamed: R56.1, U11.1 (OUT)
unnamed: R6.1, U4.53 (TIMEPULSE)
unnamed: R50.2, R51.2, U1.7 (IA35)
unnamed: Q2.5 (B), R56.2
unnamed: R51.1, R52.2
unnamed: Q2.2 (B), R63.2
unnamed: R63.1, U13.1 (OUT)
unnamed: C13.2, U4.2 (RF_IN)
unnamed: J5.SHLD1 (SHLD), J5.SHLD2 (SHLD), J5.SHLD3 (SHLD), J5.SHLD4 (SHLD), SHLD3.2
unnamed: D2.A, LED.1
PMODE0: PM0.2, R30.1, U7.45 (PMODE0)
PMODE1: PM1.2, R31.1, U7.44 (PMODE1)
PMODE2: PM2.2, R32.1, U7.43 (PMODE2)
PW1+: PW+.1, PW+.3 (1), U10.5 (VIN+), U10.6 (VIN+)
PW1-: PW-.1, PW-.3 (1), U10.7 (VIN-), U10.8 (VIN-)
PW+: J9.9 (PW+), PW+.2, PW+.4 (2)
PW-: J9.10 (PW-), PW-.2, PW-.4 (2)
PWREN: PWREN.1, R15.2, U3.3 (EN), U9.5 (2E), U9.6 (3E), U9.10 (4Z), U9.13 (1E)
RCT: C43.1, J9.5 (RCT), R35.1, R40.1
RD+: C45.2, J9.3 (RD+)
RD-: C44.2, J9.6 (RD-)
RF: C13.1, D1.1, FB1.2, J2.SIG (SIGNAL)
RXN: R39.1, U7.5 (RXN)
RXN1: C44.1, D7.4 (IO3), R39.2, R40.2
RXP: R38.1, U7.6 (RXP)
RXP1: C45.1, D7.3 (IO2), R35.2, R38.2
SD_CMD: CMD.1, J3.3 (CMD/SDI), R10.1, U9.9 (3Z)
SD_DAT0: DAT0.1, J3.7 (DAT0/SDO), R11.1, U9.2 (1Z)
SD_DAT2: DAT2.1, J3.1 (DAT2), R13.1, U9.3 (2Z)
SHIELD: J1.SHLD1 (SHLD), J1.SHLD2 (SHLD), J1.SHLD3 (SHLD), J1.SHLD4 (SHLD), SHLD1.2
TCT: C46.1, J9.4 (TCT), R43.1
TD+: D7.6 (IO4), J9.1 (TD+), R36.2, R41.1
TD-: D7.1 (IO1), J9.2 (TD-), R37.2, R42.1
TXN: R37.1, U7.1 (TXN)
TXP: R36.1, U7.2 (TXP)
VCCA: C33.1, C34.1, C35.1, C36.1, C37.1, C38.1, C39.1, D7.5 (VCC), FB2.2, R41.2, R42.2, R43.2, U7.4 (AVDD), U7.8 (AVDD), U7.11 (AVDD), U7.15 (AVDD), U7.17 (AVDD), U7.21 (AVDD), VCCA.1
VIN: D4.A, J5.VBUS1 (VBUS), J5.VBUS2 (VBUS), VIN.1
V_ANT: C11.1, FB1.1, R55.2, R59.2, R60.2, R61.2, U11.3 (+IN), U13.4 (-IN), VANT.1
V_POE: C47.1, D9.A, L1.2, LOAD.2, VPOE.1
V_USB: D5.A, D10.5 (VCC), J1.VBUS1 (VBUS), J1.VBUS2 (VBUS), VUSB.1
V_USB_2: D6.A, D8.5 (VCC), J6.VBUS1 (VBUS), J6.VBUS2 (VBUS), VUSB2.1
ZED_RX2: J13.5, R47.2, RX2.1
ZED_TX2: J13.4, R46.2, TX2.1

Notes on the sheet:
ESP32 WROOM
ESP32 USB-C
Paul Clark
v10
Reset and Boot
LED
Secondary Power
System Power
microSD
Strapping Pin Isolation
W5500
Mag Jack
ZED-F9P USB-C
VDD Range: 3.0V - 3.6V
Vin Max: 6.0V Iout Max: 700mA Vdo: 120mV @ 330mA Output Discharge: 530Ω Typ
If DTR is LOW, toggling RTS from HIGH to LOW resets to run mode. If RTS is HIGH, toggling DTR from LOW to HIGH resets to bootloader.
Pin
IO0
IO2
IO12
IO15
IO5
Run
Bootloader
Default
IO12 = MDTI, IO15 = MDTO
Boot Mode Configuration
IO0: Avoid device connections. Can be used a stat LED.
ADC2 is unavailable when WiFi is enabled.
IO12: Avoid external pullups - will cause bootloader fail.
Use boot control pins with caution: 0, 2, 5, 12, 15
IO2: Avoid external pullups - will cause bootloader fail.
IO15: Has builtin pullup at POR.
IO5: Has builtin pullup at POR.
Open jumpers to disable pull-ups
Open jumper to isolate shield
50Ω
90Ω
u-blox ZED-F9P
VCC Range: 3.0 - 3.6V

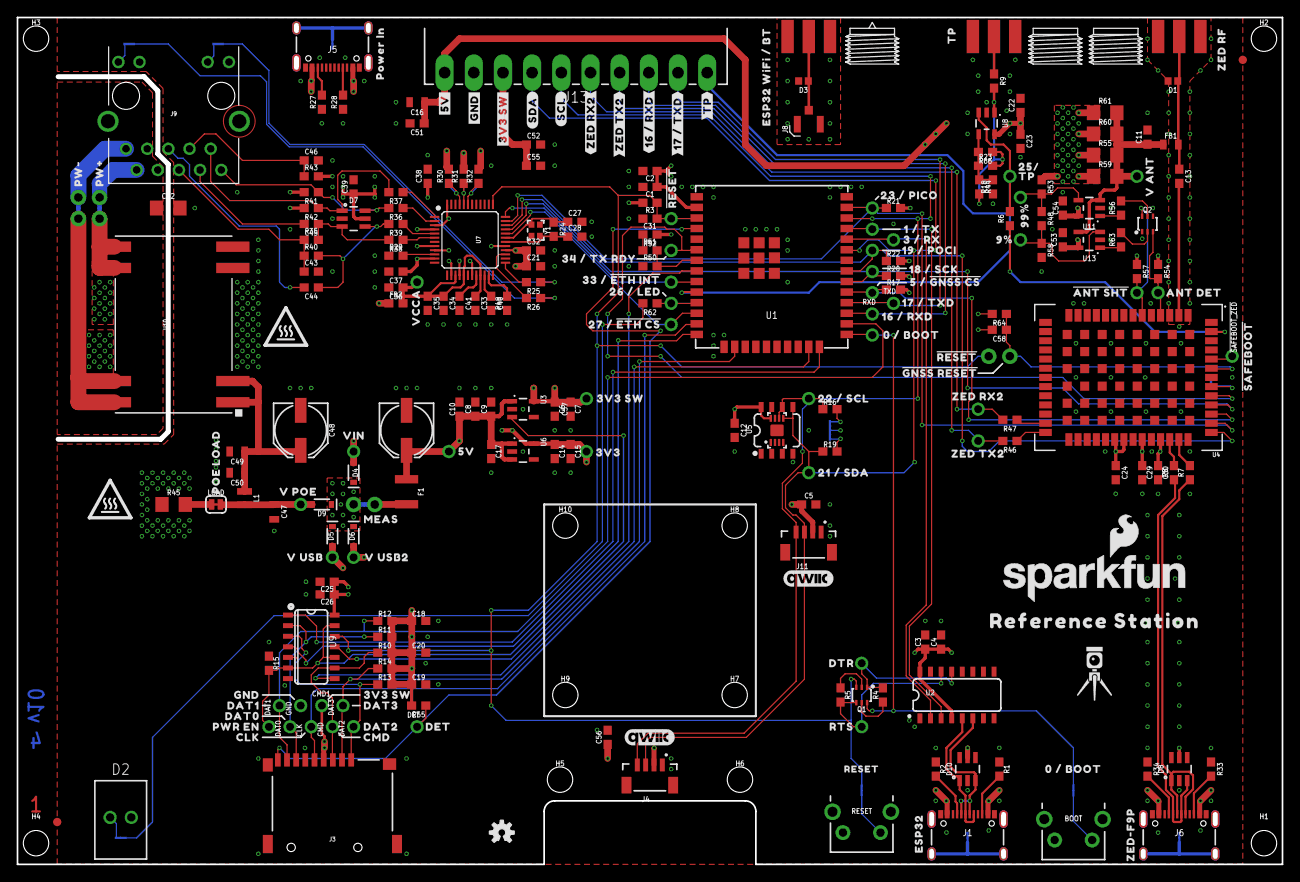
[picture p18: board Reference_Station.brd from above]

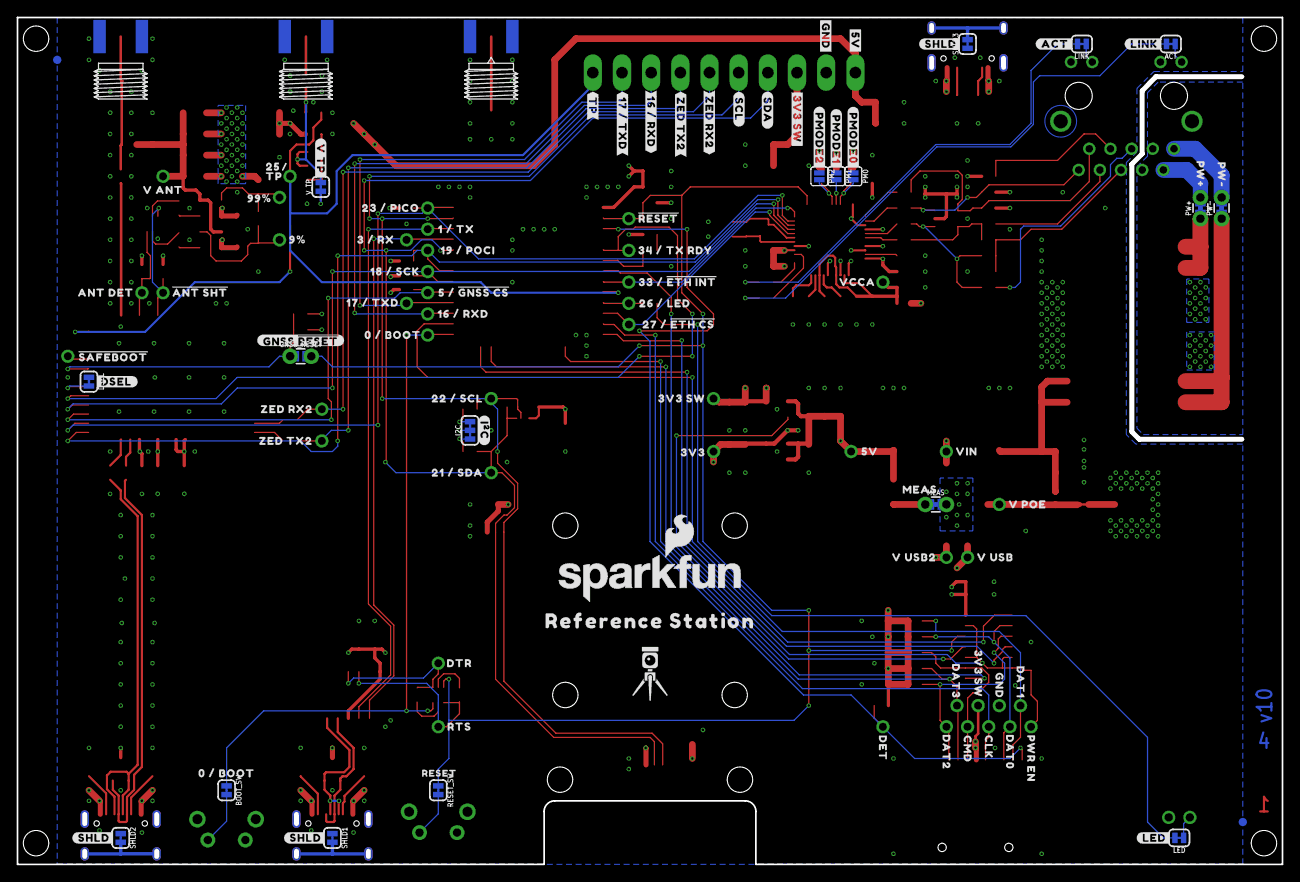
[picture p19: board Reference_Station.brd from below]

Board: 4 copper layers, 151.8 x 101.6 mm, 404 parts (98 on the bottom side), 125 nets.

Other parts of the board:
LOGO2: QWIIC_LOGO_6MM; QWIIC_6MM
LOGO7: SFE_LOGO_NAME.2_INCH; SFE_LOGO_NAME_.2
LOGO8: SFE_LOGO_FLAME.2_INCH; SFE_LOGO_FLAME_.2
U$2, U$148: RESET0
U$3, U$4, U$45: #SHLD#0
U$5, U$113: PW#0
U$6, U$114: PW#1
U$7, U$37, U$96, U$149: 0_#_BOOT0
U$8: POWER_IN0
U$9: #ACT#0
U$10: #LINK#1
U$11, U$115: #3V3_SW#0
U$12, U$124: #5V#0
U$13, U$123: #GND#6
U$14: #ZED_RX2#0
U$15, U$117: #SCL#8
U$16, U$116: #SDA#7
U$17: #ZED_RX2#3
U$18: #ZED_TX2#0
U$19: #ZED_TX2#3
U$20: #16_#_RXD#0
U$21: ESP32_WIFI_#_BT0
U$22: TP0
U$23: ZED_RF0
U$24, U$107: VCCA0
U$25, U$74, U$112: #RESET#0
U$26, U$108: 34_#_TX_RDY0
U$27, U$109: 33_#_#ETH_INT#0
U$28, U$110: 26_#_LED0
U$29, U$111: 27_#_#ETH_CS#0
U$30, U$98: 23_#_PICO23
U$31, U$89: 22_#_SCL20
U$32, U$102: 18_#_SCK6
U$33, U$101: 19_#_POCI19
U$34, U$99: 1_#_TX20
U$35, U$100: 3_#_RX20
U$36, U$97: 5_#_#GNSS_CS#1
U$38, U$90: 21_#_SDA24
U$39, U$91: ZED_RX224
U$40, U$92: ZED_TX2225
U$41, U$93: #SAFEBOOT#2226
U$42, U$94: ANT_DET2227
U$43, U$95: #ANT_SHT#2228
U$44, U$106: 9#2230
U$46: #I�C#0
U$47, U$104: 99#2230
U$48, U$103: TP2230
U$49, U$105: V_ANT2229
U$55, U$76: RTS2231
U$56, U$77: DTR2232
U$57, U$144: 3V3_SW15
U$58: #LED#2234
U$59, U$88: 3V3_SW25
U$60, U$87: 3V325
U$61, U$86: 5V25
U$62, U$84: MEAS2
U$63, U$85: VIN1
U$64, U$82: V_USB3
U$65, U$83: V_USB24
U$66, U$81: V_POE0
U$67: #PMODE0#0
U$68: #PMODE1#1
U$69: #PMODE2#2
U$70: #GNSS_#RESET##0
U$71: #V_TP#3
U$72: #DSEL#0
U$73, U$75: REFERENCE_STATION1
U$78: ESP320
U$79: ZED#F9P321
U$80, U$141: PWR_EN2233
U$118: #16_#_RXD#17
U$119: #17_#_TXD#0
U$120: #17_#_TXD#18
U$121: #TP#0
U$122: #TP#1
U$125, U$126: 16_#_RXD18
U$127, U$128: 17_#_TXD0
U$129, U$139: CLK13
U$130, U$138: CMD14
U$131, U$142: DAT10
U$132, U$140: DAT011
U$133, U$145: DAT315
U$134, U$137: DAT2316
U$135, U$143: GND12
U$136: POE_LOAD0
U$146, U$147: HIGH_TEMP_WARNING
U$150, U$151: 250
U$152, U$153: RTK5#SVG0
U$154: #GNSS_RESET#0
U$155, U$156: DET0

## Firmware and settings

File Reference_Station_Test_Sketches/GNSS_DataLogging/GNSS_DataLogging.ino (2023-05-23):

/*
  SparkFun GNSS Reference Station Test Sketch

  Configuring the GNSS to automatically send RXM SFRBX and RAWX reports at 20Hz over SPI
  and log them to file on SD card using full 4-bit SDIO. Also (optionally) logs NMEA and RTCM.

  Memory use:
  GNSS file buffer: 65535
  GNSS RTCM buffer: 4096
  Intermediate myBuffer: 512

  License: MIT. Please see LICENSE.md for more details

  Pin Allocations:
  D0  : Boot + Boot Button
  D1  : Serial TX (CH340 RX)
  D2  : SDIO DAT0 - via 74HC4066 switch
  D3  : Serial RX (CH340 TX)
  D4  : SDIO DAT1
  D5  : GNSS Chip Select
  D12 : SDIO DAT2 - via 74HC4066 switch
  D13 : SDIO DAT3
  D14 : SDIO CLK
  D15 : SDIO CMD - via 74HC4066 switch
  D16 : Serial1 RXD
  D17 : Serial1 TXD
  D18 : SPI SCK
  D19 : SPI POCI
  D21 : I2C SDA
  D22 : I2C SCL
  D23 : SPI PICO
  D25 : GNSS Time Pulse
  D26 : STAT LED
  D27 : Ethernet Chip Select
  D32 : PWREN
  D33 : Ethernet Interrupt
  A34 : GNSS TX RDY
  A35 : Board Detect (1.1V)
*/

#define DISABLE_NMEA 0 // Change this to 1 to disable NMEA
#define DISABLE_RTCM 0 // Change this to 1 to disable RTCM

const int GNSS_CS = 5; // Chip select for the GNSS SPI interface
const int ETHERNET_CS = 27; // Chip select for the WizNet 5500
const int PWREN = 32; // 3V3_SW and SDIO Enable
const int STAT_LED = 26;

#include "FS.h"
#include "SD_MMC.h"
File myFile;

#define sdWriteSize 512     // Write data to the SD card in blocks of n*512 bytes
uint8_t *myBuffer;          // Use myBuffer to hold the data while we write it to SD card

#include <SPI.h>
#define spiPort SPI

#include <SparkFun_u-blox_GNSS_v3.h> //Click here to get the library: http://librarymanager/All#SparkFun_u-blox_GNSS_v3
SFE_UBLOX_GNSS_SPI myGNSS;

#define fileBufferSize 65535 // Allocate RAM for UBX/RTCM/NMEA message storage
#define rtcmBufferSize 4096  // Allocate RAM for intermediate RTCM message storage
#define navRate 20           // Set the Nav Rate (Frequency) to 20Hz

unsigned long lastPrint; // Record when the last Serial print took place

// Note: we'll keep a count of how many SFRBX and RAWX messages arrive - but the count will not be completely accurate.
// If two or more SFRBX messages arrive together as a group and are processed by one call to checkUblox, the count will
// only increase by one.

int numSFRBX = 0; // Keep count of how many SFRBX message groups have been received (see note above)
int numRAWX = 0; // Keep count of how many RAWX message groups have been received (see note above)

// Callback: newSFRBX will be called when new RXM SFRBX data arrives
// See u-blox_structs.h for the full definition of UBX_RXMSFRBX_data_t
//         _____  You can use any name you like for the callback. Use the same name when you call setAutoRXMSFRBXcallback
//        /                  _____  This _must_ be UBX_RXM_SFRBX_data_t
//        |                 /               _____ You can use any name you like for the struct
//        |                 |              /
//        |                 |              |
void newSFRBX(UBX_RXM_SFRBX_data_t *ubxDataStruct)
{
  numSFRBX++; // Increment the count
}

// Callback: newRAWX will be called when new RXM RAWX data arrives
// See u-blox_structs.h for the full definition of UBX_RXMRAWX_data_t
//         _____  You can use any name you like for the callback. Use the same name when you call setAutoRXMRAWXcallback
//        /             _____  This _must_ be UBX_RXM_RAWX_data_t
//        |            /                _____ You can use any name you like for the struct
//        |            |               /
//        |            |               |
void newRAWX(UBX_RXM_RAWX_data_t *ubxDataStruct)
{
  numRAWX++; // Increment the count
}

void setup()
{
  pinMode(GNSS_CS, OUTPUT);
  digitalWrite(GNSS_CS, HIGH);
  pinMode(ETHERNET_CS, OUTPUT);
  digitalWrite(ETHERNET_CS, HIGH);
  pinMode(PWREN, OUTPUT);
  digitalWrite(PWREN, HIGH);
  pinMode(STAT_LED, OUTPUT);
  digitalWrite(STAT_LED, LOW);

  delay(1000);

  Serial.begin(115200);
  Serial.println("SparkFun Reference Station - Test Sketch");

  // -=-=-=-=-=-=-=-=-=-=-=-=-=-=-=-=-=-=-=-=-=-=-=
  // Initialize the GNSS

  spiPort.begin();

  Serial.println(F("Initializing the GNSS..."));

  //myGNSS.enableDebugging(); // Uncomment this line to see helpful debug messages on Serial

  myGNSS.setFileBufferSize(fileBufferSize); // setFileBufferSize must be called _before_ .begin
#if !DISABLE_RTCM
  myGNSS.setRTCMBufferSize(rtcmBufferSize); // setRTCMBufferSize must be called _before_ .begin
#endif

  // Connect to the u-blox module using SPI port, csPin and speed setting
  // ublox devices generally work up to 5MHz. We'll use 4MHz for this example:
  bool begun = false;
  do
  {
    begun = myGNSS.begin(spiPort, GNSS_CS, 4000000);
    if (!begun)
    {
      Serial.println(F("u-blox GNSS not detected on SPI bus."));
      delay(1000);
    }
  }
  while (!begun);
  
  // -=-=-=-=-=-=-=-=-=-=-=-=-=-=-=-=-=-=-=-=-=-=-=
  // Wait for a 3D fix. Get the date and time for the log file

  //myGNSS.factoryDefault(); delay(5000); // Uncomment this line to reset the module back to its factory defaults

#if DISABLE_NMEA && DISABLE_RTCM
  myGNSS.setSPIOutput(COM_TYPE_UBX); //Set the SPI port to output UBX only
#elif DISABLE_RTCM
  myGNSS.setSPIOutput(COM_TYPE_UBX | COM_TYPE_NMEA); //Set the SPI port to output UBX and NMEA messages
#elif DISABLE_NMEA
  myGNSS.setSPIOutput(COM_TYPE_UBX | COM_TYPE_RTCM3); //Set the SPI port to output UBX and RTCM messages
#else
  myGNSS.setSPIOutput(COM_TYPE_UBX | COM_TYPE_NMEA | COM_TYPE_RTCM3); //Set the SPI port to output UBX, NMEA and RTCM messages
#endif

  //myGNSS.saveConfigSelective(VAL_CFG_SUBSEC_IOPORT); //Optional: save (only) the communications port settings to flash and BBR

  Serial.print(F("Waiting for a 3D fix"));
  delay(100);

  uint8_t fix = 0;

  do
  {
    fix = myGNSS.getFixType();
    delay(1000);
    Serial.print(F("."));
  }
  while ( fix != 3 ); // Wait for a 3D fix

  Serial.println();

  uint16_t y = myGNSS.getYear();
  uint8_t M = myGNSS.getMonth();
  uint8_t d = myGNSS.getDay();
  uint8_t h = myGNSS.getHour();
  uint8_t m = myGNSS.getMinute();
  uint8_t s = myGNSS.getSecond();

  char szBuffer[40] = {'\0'};
  snprintf(szBuffer, sizeof(szBuffer), "/%04d%02d%02d%02d%02d%02d.ubx", y, M, d, h, m, s);

  Serial.println(F("GNSS initialized."));

  // -=-=-=-=-=-=-=-=-=-=-=-=-=-=-=-=-=-=-=-=-=-=-=
  // Initialize the SD card. Open the log file

  Serial.println(F("Initializing SD card..."));

  // Begin the SD card
  if(!SD_MMC.begin())
  {
    Serial.println(F("Card mount failed. Freezing..."));
    while(1);
  }

  // Open the log file for writing
  Serial.printf("Log file is: %s\r\n", szBuffer);
  myFile = SD_MMC.open((const char *)szBuffer, FILE_WRITE);
  if(!myFile)
  {
    Serial.println(F("Failed to open log file for writing. Freezing..."));
    while(1);
  }

  Serial.println(F("SD card initialized."));

  // -=-=-=-=-=-=-=-=-=-=-=-=-=-=-=-=-=-=-=-=-=-=-=
  // Wait for a key press

  while (Serial.available()) // Make sure the Serial buffer is empty
  {
    Serial.read();
  }

  Serial.println(F("Press any key to start logging."));

  while (!Serial.available()) // Wait for the user to press a key
  {
    ; // Do nothing
  }

  delay(100); // Wait, just in case multiple characters were sent

  while (Serial.available()) // Empty the Serial buffer
  {
    Serial.read();
  }

  // -=-=-=-=-=-=-=-=-=-=-=-=-=-=-=-=-=-=-=-=-=-=-=
  // Enable RAWX and SFRBX

  myGNSS.setAutoRXMSFRBXcallbackPtr(&newSFRBX); // Enable automatic RXM SFRBX messages at the navigation rate with callback to newSFRBX

  myGNSS.logRXMSFRBX(); // Enable RXM SFRBX data logging

  myGNSS.setAutoRXMRAWXcallbackPtr(&newRAWX); // Enable automatic RXM RAWX messages at the navigation rate with callback to newRAWX

  myGNSS.logRXMRAWX(); // Enable RXM RAWX data logging

  myBuffer = new uint8_t[sdWriteSize]; // Create our own buffer to hold the data while we write it to SD card  

#if !DISABLE_NMEA
  myGNSS.newCfgValset(VAL_LAYER_RAM);
  myGNSS.addCfgValset(UBLOX_CFG_MSGOUT_NMEA_ID_GGA_SPI, navRate); // Ensure the GxGGA (Global positioning system fix data) message is enabled. Send at 1Hz.
  myGNSS.addCfgValset(UBLOX_CFG_MSGOUT_NMEA_ID_GSA_SPI, navRate); // Ensure the GxGSA (GNSS DOP and Active satellites) message is enabled. Send at 1Hz.
  myGNSS.addCfgValset(UBLOX_CFG_MSGOUT_NMEA_ID_GSV_SPI, navRate); // Ensure the GxGSV (GNSS satellites in view) message is enabled. Send at 1Hz.
  myGNSS.addCfgValset(UBLOX_CFG_MSGOUT_NMEA_ID_GST_SPI, navRate); // Ensure the GxGST (Position error statistics) message is enabled. Send at 1Hz.
  myGNSS.addCfgValset(UBLOX_CFG_MSGOUT_NMEA_ID_RMC_SPI, navRate); // Ensure the GxRMC (Recommended minimum: position, velocity and time) message is enabled. Send at 1Hz.
  myGNSS.sendCfgValset();

  myGNSS.setNMEALoggingMask(SFE_UBLOX_FILTER_NMEA_GGA | SFE_UBLOX_FILTER_NMEA_GSA | SFE_UBLOX_FILTER_NMEA_GSV | SFE_UBLOX_FILTER_NMEA_GST | SFE_UBLOX_FILTER_NMEA_RMC); // Log only these NMEA messages
#endif

#if !DISABLE_RTCM
  myGNSS.newCfgValset(VAL_LAYER_RAM);
  myGNSS.addCfgValset(UBLOX_CFG_MSGOUT_RTCM_3X_TYPE4072_0_SPI, navRate); // Enable RTCM3 4072_0 at 1Hz. This is output without needing a survey-in.
  myGNSS.sendCfgValset();

  myGNSS.setRTCMLoggingMask(SFE_UBLOX_FILTER_RTCM_TYPE4072_0); // Log only this RTCM3 message
#endif

  myGNSS.setNavigationFrequency(navRate); // Set navigation rate

  Serial.println(F("Press any key to stop logging."));

  lastPrint = millis(); // Initialize lastPrint
}

void loop()
{
  // =-=-=-=-=-=-=-=-=-=-=-=-=-=-=-=-=-=-=-=-

  myGNSS.checkUblox(); // Check for the arrival of new data and process it.
  myGNSS.checkCallbacks(); // Check if any callbacks are waiting to be processed.

  // =-=-=-=-=-=-=-=-=-=-=-=-=-=-=-=-=-=-=-=-

  while (myGNSS.fileBufferAvailable() >= sdWriteSize) // Check to see if we have at least sdWriteSize waiting in the buffer
  {
    digitalWrite(STAT_LED, HIGH); // Flash the STAT LED each time we write to the SD card

    myGNSS.extractFileBufferData(myBuffer, sdWriteSize); // Extract exactly sdWriteSize bytes from the UBX file buffer and put them into myBuffer

    myFile.write(myBuffer, sdWriteSize); // Write exactly sdWriteSize bytes from myBuffer to the ubxDataFile on the SD card

    // In case the SD writing is slow or there is a lot of data to write, keep checking for the arrival of new data
    myGNSS.checkUblox(); // Check for the arrival of new data and process it.
    myGNSS.checkCallbacks(); // Check if any callbacks are waiting to be processed.

    digitalWrite(STAT_LED, LOW); // Turn the STAT LED off again
  }

  // =-=-=-=-=-=-=-=-=-=-=-=-=-=-=-=-=-=-=-=-

  if (millis() > (lastPrint + 1000)) // Print the message count once per second
  {
    uint16_t maxBufferBytes = myGNSS.getMaxFileBufferAvail(); // Get how full the file buffer has been (not how full it is now)
    float bufferHigh = 100.0 * (float)maxBufferBytes / (float)fileBufferSize;

    Serial.print(F("Message groups received: SFRBX: ")); // Print how many message groups have been received (see note above)
    Serial.print(numSFRBX);
    Serial.print(F(" RAWX: "));
    Serial.print(numRAWX);
    Serial.print(F("  \tBuffer high tide: "));
    Serial.print(bufferHigh, 1); // It is a fun thing to watch how full the buffer gets
    if (bufferHigh > 90.)
      Serial.println(F("%!!"));
    else if (bufferHigh > 80.)
      Serial.println(F("%!"));
    else
      Serial.println(F("%"));

    lastPrint = millis(); // Update lastPrint
  }

  // =-=-=-=-=-=-=-=-=-=-=-=-=-=-=-=-=-=-=-=-

  if (Serial.available()) // Check if the user wants to stop logging
  {
    uint16_t remainingBytes = myGNSS.fileBufferAvailable(); // Check if there are any bytes remaining in the file buffer

    while (remainingBytes > 0) // While there is still data in the file buffer
    {
      digitalWrite(STAT_LED, HIGH); // Flash the STAT LED while we write to the SD card

      uint16_t bytesToWrite = remainingBytes; // Write the remaining bytes to SD card sdWriteSize bytes at a time
      if (bytesToWrite > sdWriteSize)
      {
        bytesToWrite = sdWriteSize;
      }

      myGNSS.extractFileBufferData(myBuffer, bytesToWrite); // Extract bytesToWrite bytes from the UBX file buffer and put them into myBuffer

      myFile.write(myBuffer, bytesToWrite); // Write bytesToWrite bytes from myBuffer to the ubxDataFile on the SD card

      remainingBytes -= bytesToWrite; // Decrement remainingBytes
    }

    digitalWrite(STAT_LED, LOW); // Turn the STAT LED off

    myFile.close(); // Close the data file

    myGNSS.setNavigationFrequency(1); // Set navigation rate to 1Hz

    myGNSS.newCfgValset(VAL_LAYER_RAM);
    myGNSS.addCfgValset(UBLOX_CFG_MSGOUT_UBX_RXM_RAWX_SPI, 0);
    myGNSS.addCfgValset(UBLOX_CFG_MSGOUT_UBX_RXM_SFRBX_SPI, 0);
    myGNSS.addCfgValset(UBLOX_CFG_MSGOUT_RTCM_3X_TYPE4072_0_SPI, 0);
    myGNSS.sendCfgValset();

    myGNSS.setSPIOutput(COM_TYPE_UBX | COM_TYPE_NMEA | COM_TYPE_RTCM3); // Re-enable NMEA and RTCM

    Serial.println(F("Logging stopped. Freezing..."));
    while(1); // Do nothing more
  }

  // =-=-=-=-=-=-=-=-=-=-=-=-=-=-=-=-=-=-=-=-
}

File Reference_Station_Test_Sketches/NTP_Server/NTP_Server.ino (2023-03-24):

/*
  SparkFun GNSS Reference Station Test Sketch

  License: MIT. Please see LICENSE.md for more details

  Pin Allocations:
  D0  : Boot + Boot Button
  D1  : Serial TX (CH340 RX)
  D2  : SDIO DAT0 - via 74HC4066 switch
  D3  : Serial RX (CH340 TX)
  D4  : SDIO DAT1
  D5  : GNSS Chip Select
  D12 : SDIO DAT2 - via 74HC4066 switch
  D13 : SDIO DAT3
  D14 : SDIO CLK
  D15 : SDIO CMD - via 74HC4066 switch
  D16 : Serial1 RXD
  D17 : Serial1 TXD
  D18 : SPI SCK
  D19 : SPI POCI
  D21 : I2C SDA
  D22 : I2C SCL
  D23 : SPI PICO
  D25 : GNSS Time Pulse
  D26 : STAT LED
  D27 : Ethernet Chip Select
  D32 : PWREN
  D33 : Ethernet Interrupt
  A34 : GNSS TX RDY
  A35 : Board Detect (1.1V)
  A36 : microSD card detect
  A39 : Unused analog pin - used to generate random values for SSL
*/

#include <SPI.h> // Needed for SPI to GNSS

#include <Ethernet.h> // http://librarymanager/All#Arduino_Ethernet
//#include <EthernetLarge.h> // https://github.com/OPEnSLab-OSU/EthernetLarge
//#include <EthernetUdp.h>
//#include "utility/w5100.h"

#include <SSLClient.h> //http://librarymanager/All#SSLClient
#include "sslCerts.h"

#include <Esp.h>
#include <ESP32Time.h> //http://librarymanager/All#ESP32Time by FBiego v2.0.0
#include "time.h"
#include <sys/time.h>
ESP32Time rtc;

// =-=-=-=-=-=-=-=-=-=-=-=-=-=-=-=-=-=-=-=-=-=-=-=-=-=-=-=-=-=-=-=-=-=-=-=-=-=-=-=-=-=-=-=-=-=-=-=-=-=-
// Pin definitions

const int GNSS_CS = 5; // Chip select for the GNSS SPI interface
const int ETHERNET_CS = 27; // Chip select for the WizNet 5500
const int PWREN = 32; // 3V3_SW and SDIO Enable
const int ETHERNET_INT = 33;
const int STAT_LED = 26;
const int GNSS_INT = 25;
const int ANALOG_RANDOM = 39;

// =-=-=-=-=-=-=-=-=-=-=-=-=-=-=-=-=-=-=-=-=-=-=-=-=-=-=-=-=-=-=-=-=-=-=-=-=-=-=-=-=-=-=-=-=-=-=-=-=-=-
// GNSS object

#include <SparkFun_u-blox_GNSS_v3.h> //http://librarymanager/All#SparkFun_u-blox_GNSS_v3
SFE_UBLOX_GNSS_SUPER theGNSS;

// Uncomment the following line to include the position in the AssistNow data request
// This also helps keep the Assist Now data requests under 2KB
#define USE_SERVER_ASSISTANCE

// =-=-=-=-=-=-=-=-=-=-=-=-=-=-=-=-=-=-=-=-=-=-=-=-=-=-=-=-=-=-=-=-=-=-=-=-=-=-=-=-=-=-=-=-=-=-=-=-=-=-
// NTP port server (UDP)

#define NTP_PORT 123

class derivedEthernetUDP : public EthernetUDP
{
  public:
    uint8_t getSockIndex() { return sockindex; } // sockindex is protected in EthernetUDP. A derived class can access it.
};
derivedEthernetUDP timeServer;

#define fixedIPAddress
#ifdef fixedIPAddress
IPAddress myIPAddress = { 192, 168, 0, 123 }; // Use this IP Address - not DHCP

#define useDNS
#ifdef useDNS
IPAddress myDNS = { 194, 168, 4, 100 };

#define useGateway
#ifdef useGateway
IPAddress myGateway = { 192, 168, 0, 1 };

#define useSubnetMask
#ifdef useSubnetMask
IPAddress mySubnetMask = { 255, 255, 255, 0 };

#endif

#endif

#endif

#endif

// TODO: Add gateway and subnet options

// =-=-=-=-=-=-=-=-=-=-=-=-=-=-=-=-=-=-=-=-=-=-=-=-=-=-=-=-=-=-=-=-=-=-=-=-=-=-=-=-=-=-=-=-=-=-=-=-=-=-
// Assist Now (HTTPS)

EthernetClient baseAssistNowClient;
SSLClient assistNowClient(baseAssistNowClient, TAs, (size_t)TAs_NUM, ANALOG_RANDOM);

// =-=-=-=-=-=-=-=-=-=-=-=-=-=-=-=-=-=-=-=-=-=-=-=-=-=-=-=-=-=-=-=-=-=-=-=-=-=-=-=-=-=-=-=-=-=-=-=-=-=-
// Globals

volatile bool syncRTC = true;                   // Flag to indicate if the RTC should be sync'd
volatile struct timeval gnssTv;                 // This will hold the GNSS time
volatile struct timeval gnssSyncTv;             // This will hold the time the GNSS was last sync'd
volatile struct timeval ethernetTv;             // This will hold the time the Ethernet packet arrived
volatile bool timeFullyResolved = false;        // Record if GNSS time is fully resolved
volatile unsigned long lastRTCsync = 0;         // Record the millis when the RTC is sync'd
volatile unsigned long gnssUTCreceived = 0;     // Record the millis when GNSS time is received
const unsigned long resyncAfterMillis = 60000;  // Re-sync every minute - for testing only. Once per hour should be more than adequate
const unsigned long gnssStaleAfter = 999;       // Treat GNSS time as stale after this many millis
volatile uint32_t tAcc;                         // Record the GNSS time accuracy
const uint32_t tAccLimit = 5000;                // Only sync if the time accuracy estimate is better than 5us (5000 nanoseconds)
volatile uint8_t sockIndex;                     // The W5500 socket index for the timeServer - so we can enable and read the correct interrupt

// =-=-=-=-=-=-=-=-=-=-=-=-=-=-=-=-=-=-=-=-=-=-=-=-=-=-=-=-=-=-=-=-=-=-=-=-=-=-=-=-=-=-=-=-=-=-=-=-=-=-
// Time Pulse ISR
// Triggered by the rising edge of the time pulse signal, indicates the top-of-second.
// Set the ESP32 RTC to UTC

void tpISR()
{
  unsigned long millisNow = millis();
  if (syncRTC) // Only sync if syncRTC is true
  {
    if ((lastRTCsync + resyncAfterMillis) < millisNow) // Only sync if it is more than resyncAfterMillis since the last sync
    {
      if (millisNow < (gnssUTCreceived + gnssStaleAfter)) // Only sync if the GNSS time is not stale
      {
        if (timeFullyResolved) // Only sync if GNSS time is fully resolved
        {
          if (tAcc < tAccLimit) // Only sync if the tAcc is better than tAccLimit
          {
            rtc.setTime(gnssTv.tv_sec, gnssTv.tv_usec); // Sync the RTC
            lastRTCsync = millisNow; // Update lastSync
            gnssSyncTv.tv_sec = gnssTv.tv_sec; // Store the timeval of the sync
            gnssSyncTv.tv_usec = gnssTv.tv_usec;
          }
        }
      }
    }
  }

  digitalWrite(STAT_LED, !digitalRead(STAT_LED)); // Flash the LED to indicate TP interrupts are being received
}

// =-=-=-=-=-=-=-=-=-=-=-=-=-=-=-=-=-=-=-=-=-=-=-=-=-=-=-=-=-=-=-=-=-=-=-=-=-=-=-=-=-=-=-=-=-=-=-=-=-=-
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

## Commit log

2022-11-29 Initial commit for proto review
    [CORS_Time_Reference-Panel.GBL, CORS_Time_Reference-Panel.GBO, CORS_Time_Reference-Panel.GBP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]
2022-12-02 v01 after proto review
    [CORS_Time_Reference-Panel.brd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]
2022-12-02 Update schematic
2022-12-02 Add front and rear panel v2
    [SparkFun_HF-A_Custom__Front_Panel__v2.dxf, SparkFun_HF-A_Custom__Rear_Panel__v2.dxf]
2022-12-05 Add SMA Jig
    [SMA_Jig_Base.dxf]
2022-12-08 Add CONN-17279
    [CORS_Time_Reference-Panel.brd, CORS_Time_Reference.brd, CORS_Time_Reference.sch]
2022-12-28 Add front panel PCB
    [CORS_Front_Panel.brd, CORS_Front_Panel.sch]
2022-12-29 Add rear panel and gerbers
    [CORS_Front_Panel.brd, CORS_Rear_Panel.brd, CORS_Rear_Panel.sch]
2022-12-29 Add panel png's and dxf's
    [CORS_Front_Panel.brd, CORS_Front_Panel.dxf, CORS_Rear_Panel.dxf]
2022-12-29 Add panel sticker files
    [CORS_Front_Panel.brd, CORS_Front_Panel.dxf, CORS_Front_Panel.sch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]
2022-12-30 Update OLED and Ethernet
    [CORS_Front_Panel.brd, CORS_Front_Panel.sch, CORS_Front_Panel_Sticker.dxf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]
2022-12-30 Add SMA alignment jig
    [SMA_Alignment_Jig.brd, SMA_Alignment_Jig.sch]
2022-12-30 Add sticker alignment jig
    [Sticker_Alignment_Jig.brd, Sticker_Alignment_Jig.sch]
2023-01-11 Change ESP32 SMA to RP
    [CORS_Time_Reference.brd, CORS_Time_Reference.sch]
2023-02-09 Shrink OLED cut-out by 0.3mm
2023-02-09 Reduce USB clearance to +/- 0.25mm (was +/- 0.5mm)
2023-02-09 Reduce button hole size
2023-02-09 Reduce LED hole size
2023-02-09 Reduce SMA hole diameter
2023-02-09 Reduce panel hole spacing by 0.3mm to match as-manufactured hole positions
2023-02-10 Update sticker alignment jig
    [SMA_Jig_Base.dxf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]
2023-02-10 Update panels
    [CORS_Front_Panel.brd, CORS_Front_Panel.sch, CORS_Rear_Panel.brd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]
2023-02-10 Update stickers
    [CORS_Front_Panel.brd, CORS_Front_Panel.sch, CORS_Front_Panel_Sticker_2.dxf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]
2023-02-10 v10 Hardware
    [CORS_Time_Reference-Panel.GBL, CORS_Time_Reference-Panel.GBO, CORS_Time_Reference-Panel.GBS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]
2023-02-13 Improve TP output at 5V
    [Reference_Station-Panel.brd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]
2023-03-21 Move BOOT / MODE button further out. Update panels and stickers
    [CORS_Front_Panel.brd, CORS_Front_Panel_Sticker_2.dxf, CORS_Rear_Panel_Sticker_2.dxf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]
2023-03-22 NTP_Server updates for ESP32 v2.0.2
2023-04-24 Replace OPA344 with MCP6021T-E/OT
    [Reference_Station-Panel.brd, Reference_Station.brd, Reference_Station.sch]
2023-05-17 Change LED to GREEN
    [Reference_Station-Panel.brd, Reference_Station.brd, Reference_Station.sch]

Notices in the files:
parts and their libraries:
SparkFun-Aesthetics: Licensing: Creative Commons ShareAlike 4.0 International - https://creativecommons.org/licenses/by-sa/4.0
